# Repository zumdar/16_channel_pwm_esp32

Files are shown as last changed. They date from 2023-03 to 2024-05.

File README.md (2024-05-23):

# 16 Channel PWM led dimming board for ESP32

this repo contains the files for a 16 channel pcb to dim LEDS. 

## Description

I designed this board originally for my friend [Eddie Farr](https://www.instagram.com/freaughouse/?hl=en) for an led sculpture he is working on. I've also wanted something like this for a while to dim analog LED strips easily via WLED or ArtNet, or just plain old locally from a microcontroller.

It is designed to take in voltages from 5 to 37 Volts to power the ESP32. That way you can use this with 12 or 24 volt LEDs and dont have to deal with an extra 5V power supply to power the esp32. 

There are two separate places to put power in. 
EITHER plug 5V into the 5V side, or plug 7 - 37V into the other side. 
## pinout

LED1 = GPIO 5

LED2 = GPIO 12

LED3 = GPIO 13

LED4 = GPIO 14

LED5 = GPIO 15

LED6 = GPIO 16

LED7 = GPIO 17

LED8 = GPIO 18

LED9 = GPIO 19

LED10 = GPIO 21

LED11 = GPIO 22

LED12 = GPIO 23

LED13 = GPIO 25

LED14 = GPIO 26

LED15 = GPIO 27

LED16 = GPIO 32
## Schematic 
Rev 3
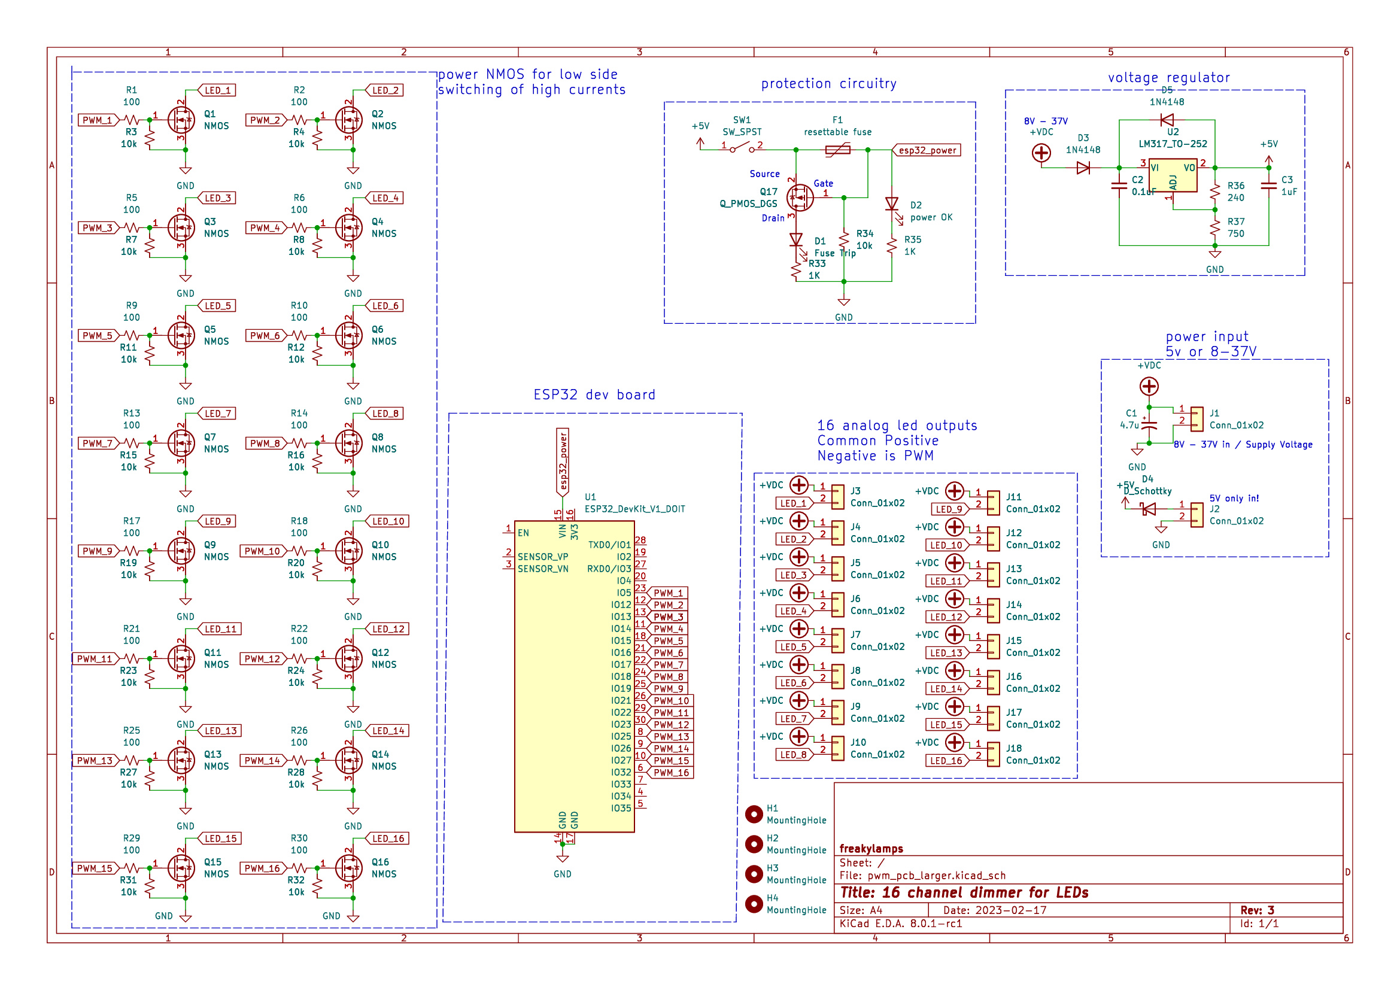
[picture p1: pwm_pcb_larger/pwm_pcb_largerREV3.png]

Rev 1 
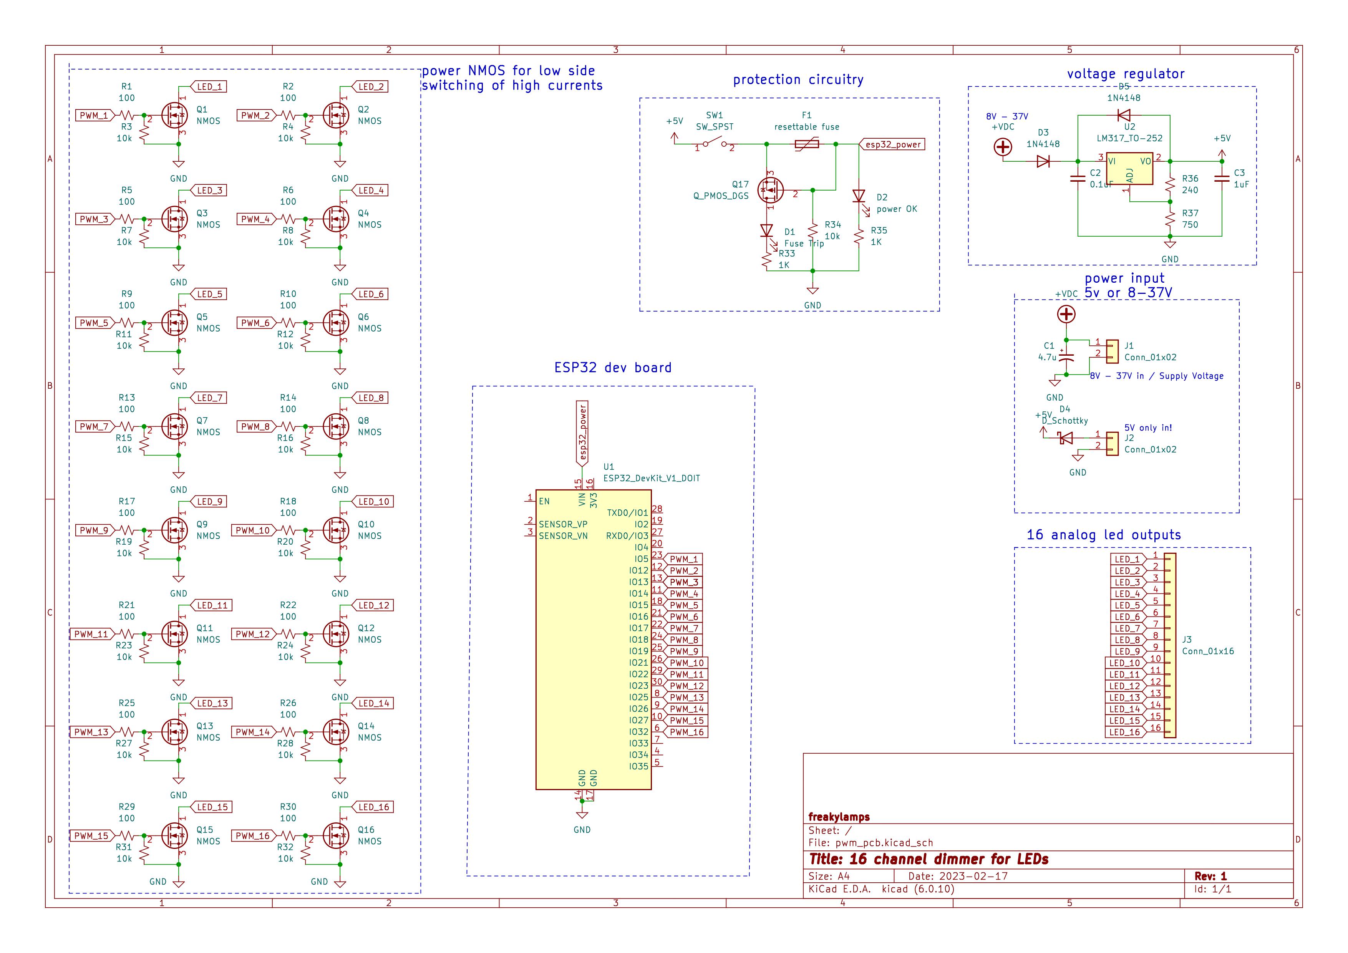
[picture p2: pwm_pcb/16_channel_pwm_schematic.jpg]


## PCB

Rev. 3 - pcb with larger transistors and larger connectors:

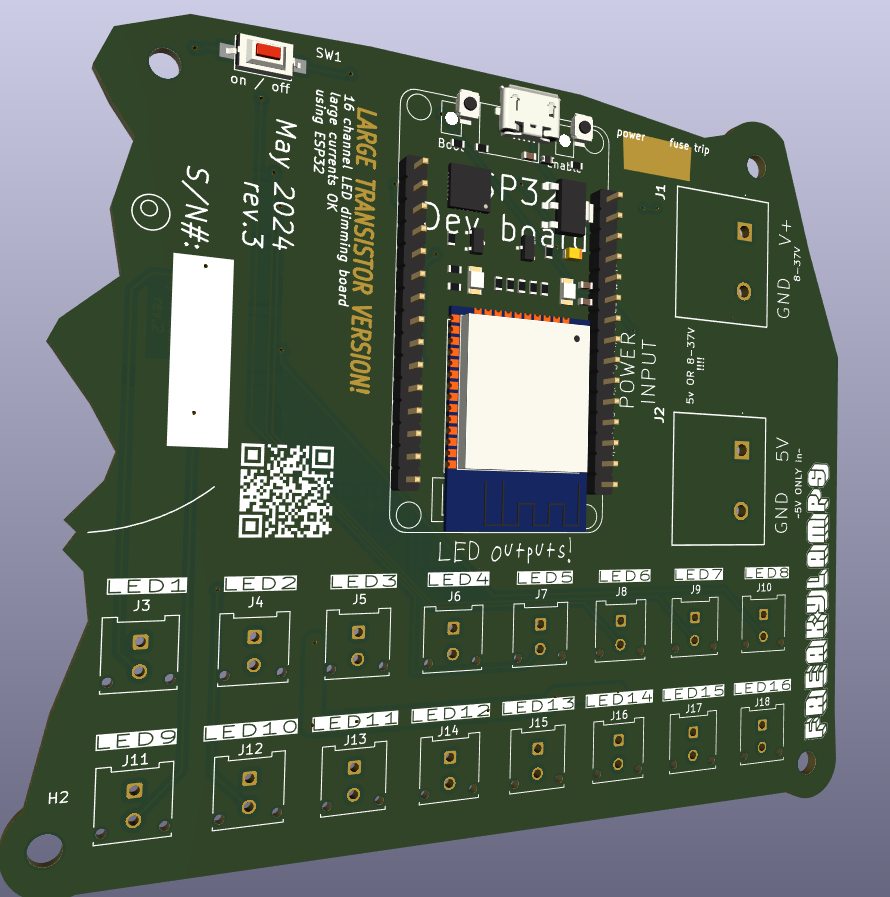
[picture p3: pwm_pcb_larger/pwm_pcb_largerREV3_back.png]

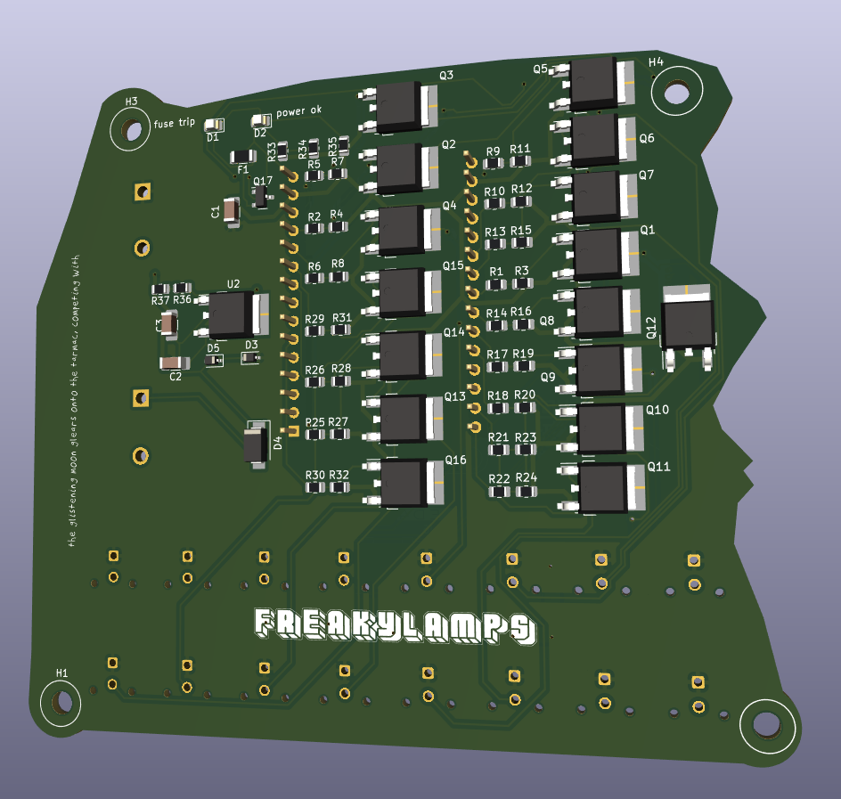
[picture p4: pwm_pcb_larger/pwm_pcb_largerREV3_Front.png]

Rev. 1 - pcb with larger transistors:

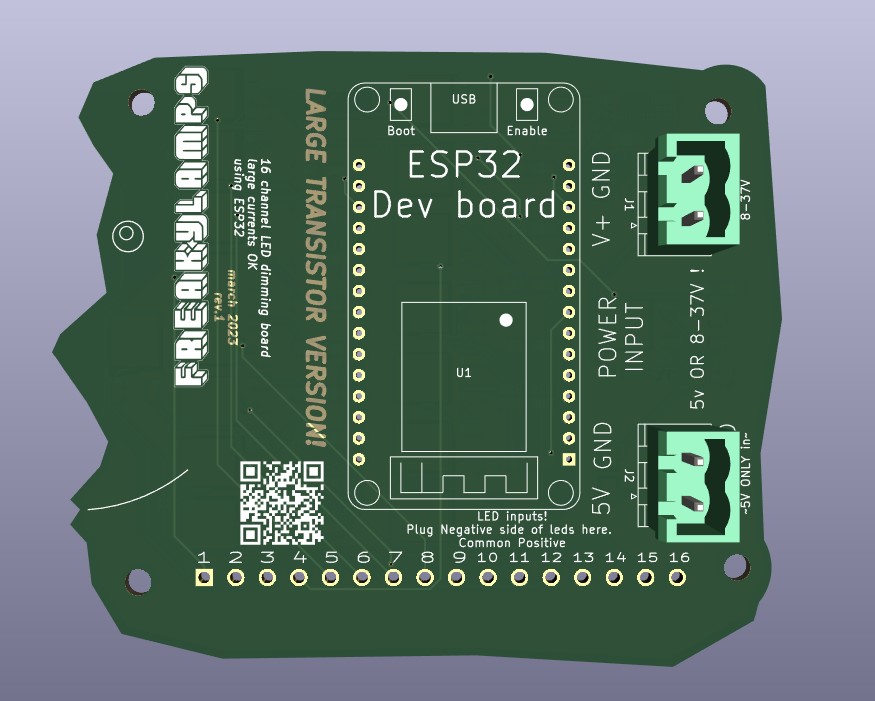
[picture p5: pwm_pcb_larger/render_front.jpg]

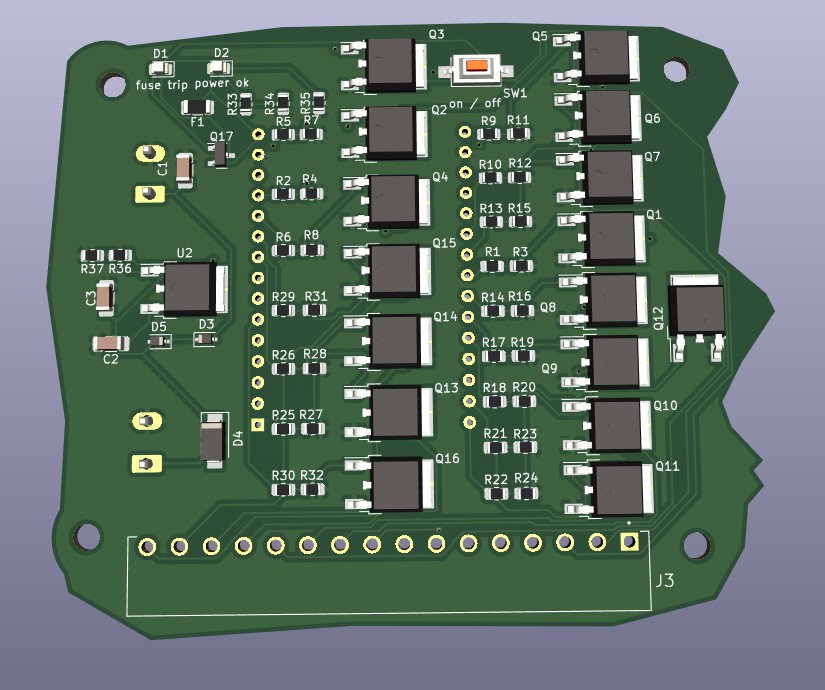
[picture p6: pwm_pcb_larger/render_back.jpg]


Rev. 1 - pcb with smaller transistors:

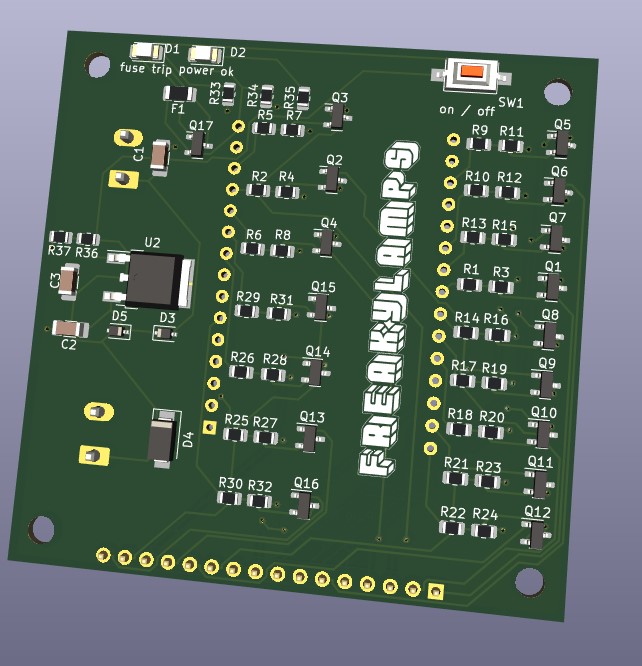
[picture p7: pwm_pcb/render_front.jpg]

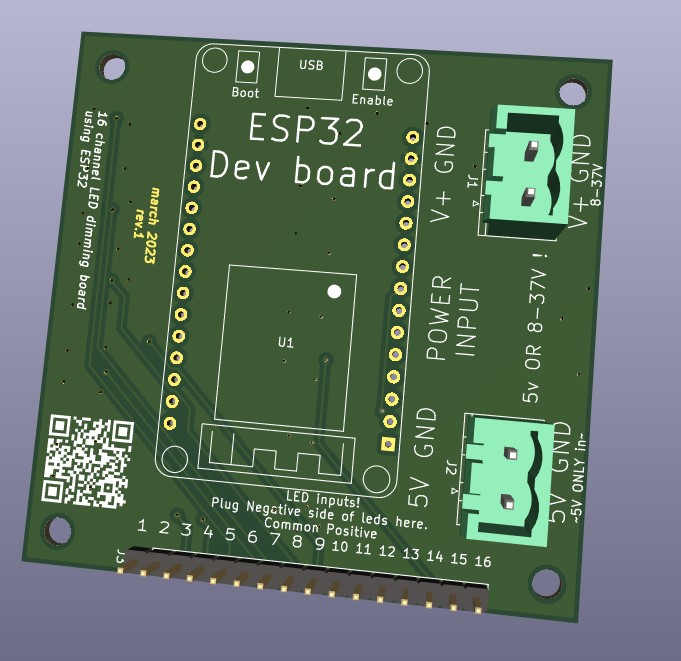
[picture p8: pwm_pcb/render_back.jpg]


## Parts references
### Connectors
- On version 1.3 we are trying out some Molex Microfit connectors
- Crimping tool - [Engineer PA09](https://www.amazon.com/ENGINEER-AWG32-AWG20-Connectors-Oil-Resistant-PA-09/dp/B002AVVO7K?th=1) 
- 
### Common parts
- [Mouser Cart](https://www.mouser.com/ProjectManager/ProjectDetail.aspx?AccessID=f114f2123e) for QTY 5 REV2 boards - this is parts not included with the JLCPCB assembly. 

- [Recommended Generic Crimper](https://www.amazon.com/ENGINEER-AWG32-AWG20-Connectors-Oil-Resistant-PA-09/dp/B002AVVO7K) for Molex Microfit Connectors

- using ESP-WROOM-32 dev board. 2.05" x 1.18" like the kind [found here](https://www.amazon.com/ESP-WROOM-32-Development-Microcontroller-Integrated-Compatible/dp/B0BK13HWBJ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)
- Both pcbs mount with M3 screws
- board has two places for power. one for 5V and one for 8V - 40V. The two connectors MSTBV/MSTBA Phoenix Type, 5.08 pitch. 
  - straight receptacle/header: [1747993 (green)](https://www.mouser.com/ProductDetail/Phoenix-Contact/1747993?qs=cq3Rj917t3li0%2FrJTXaRgg%3D%3D) or [1836561 (orange)](https://www.mouser.com/ProductDetail/Phoenix-Contact/1836561?qs=RahONj4mt5imYCprRrL9IA%3D%3D) or [1740893 (black)](https://www.mouser.com/ProductDetail/Phoenix-Contact/1740893?qs=o3rrLWFGhRnNm6PoJeAVCw%3D%3D)
  - right angle receptacle/header: [1736036 (green)](https://www.mouser.com/ProductDetail/Phoenix-Contact/1736036?qs=IGPQaF7TU6v9VVAvkUDQlA%3D%3D) or [1702878 (white)](https://www.mouser.com/ProductDetail/Phoenix-Contact/1702878?qs=2WS7V4AoKFqZwxKPPB6GZw%3D%3D) or [1876848 (orange)](https://www.mouser.com/ProductDetail/Phoenix-Contact/1876848?qs=KDxjV83btlSGzDlv5NRfLA%3D%3D)
  - terminal block plug: [Wurth 691351500002](https://www.mouser.com/ProductDetail/Wurth-Elektronik/691351500002?qs=7gQLVZk5cPkg%2FrpRGyiXgA%3D%3D) or [Kobiconn 158-P022ESDVP-E](https://www.mouser.com/ProductDetail/Kobiconn/158-P022ESDVP-E?qs=EibfsPFbZarDIylQPyTRxA%3D%3D) or [Amphenol TJ0251530000G](https://www.mouser.com/ProductDetail/Amphenol-Anytek/TJ0251530000G?qs=Mv7BduZupUjx%252Becl1KCPZg%3D%3D)
### larger pcb
- Enclosure mounts with #8 wood screws
-  the larger board uses 3.81mm pitch connector for led outputs
   - 16 channel plug -  pluggable screw terminal block - [TBP02P1-381-16BE](https://www.mouser.com/ProductDetail/490-TBP02P1-381-16BE) 
   - screw terminal receptacle/header 
[TBP02R1-381-16BE](https://www.mouser.com/ProductDetail/490-TBP02R1-381-16BE)
### smaller pcb
- smaller board uses 2.54mm connector for led outputs

## Help

Any advise for common problems or issues.

## Authors

[william kennedy](https://freakylamps.com/)

## Version History

* 1.0
    * Initial Release - March 15, 2023
* 1.1
    * new design with larger TO-252 package for NMOS - March 20, 2023
* 1.2 - april 5, 2023
  * v2 of smaller board. v1 had NMOS pinout wrong
* Rev 3 - May 22, 2024
  * large boards are now larger, using MicroFit connectors for the led outputs, terminal block for PSU inputs
  * switch is on front now
  * Q17 had pinout wrong

## License

This project is licensed under the [NAME HERE] License - see the LICENSE.md file for details

## Acknowledgments

Inspiration comes from [quinLED's analog boards](https://quinled.info/quinled-an-quad/)

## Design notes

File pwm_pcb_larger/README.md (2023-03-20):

# 16 Channel PWM led dimming board for ESP32 - larger version with TO252 package

this repo contains the files for a 16 channel pcb to dim leds using TO-252 NMOS package for more current. 

## use case 
- WLED to dim analog LED strips
- ArtNet dmx over wifi to the ESP32 to control 16 channels of led wirelessly

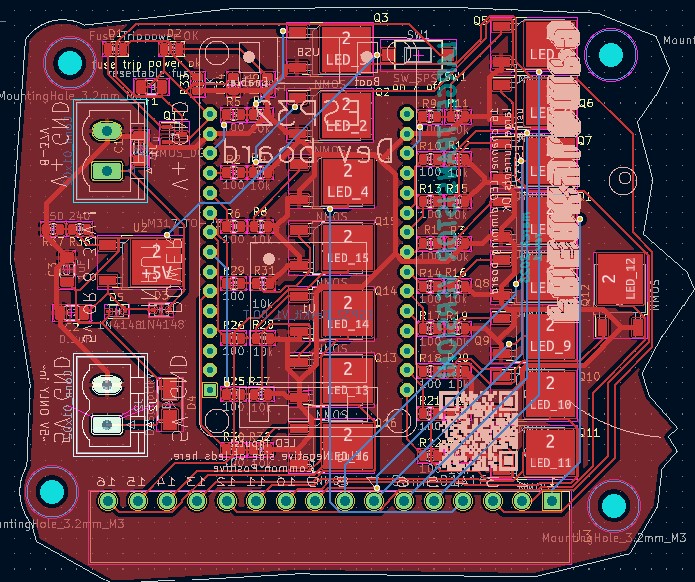
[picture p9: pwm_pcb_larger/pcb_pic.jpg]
pwm_pcb with larger transistors


## Author

[william kennedy](https://freakylamps.com/)

## Version History

* 1.1
    * Initial Release - March 20, 2023

## License

This project is licensed under the [NAME HERE] License - see the LICENSE.md file for details

## Acknowledgments

Inspiration comes from [quinLED's analog boards](https://quinled.info/quinled-an-quad/)

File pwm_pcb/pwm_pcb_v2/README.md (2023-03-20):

# 16 Channel PWM led dimming board for ESP32 - smaller version with SOT23 NMOS 

this repo contains the files for a 16 channel pcb to dim leds using sot23 NMOS package for less current. 

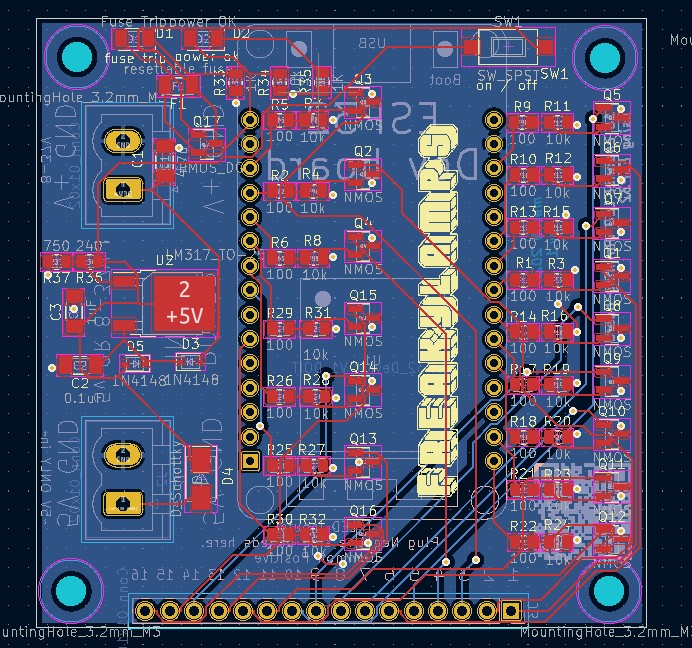
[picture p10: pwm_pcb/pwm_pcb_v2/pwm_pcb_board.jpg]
pwm pcb board


front

back

## Authors

[william kennedy](https://freakylamps.com/)

## Version History

* 1.0
    * Initial Release - March 15, 2023

## License

This project is licensed under the [NAME HERE] License - see the LICENSE.md file for details

## Acknowledgments

Inspiration, code snippets, etc.

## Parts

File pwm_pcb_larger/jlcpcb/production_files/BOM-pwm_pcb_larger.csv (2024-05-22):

Comment | Designator | Footprint | LCSC
Q_PMOS_DGS | Q17 | SOT-23 | C15127
100 | R1,R10,R13,R14,R17,R18,R2,R21,R22,R25,R26,R29,R30,R5,R6,R9 | R_0805_2012Metric | C17408
10k | R11,R12,R15,R16,R19,R20,R23,R24,R27,R28,R3,R31,R32,R34,R4,R7,R8 | R_0805_2012Metric | C17414
1K | R33,R35 | R_0805_2012Metric | C17513
240 | R36 | R_0805_2012Metric | C17572
750 | R37 | R_0805_2012Metric | C17818
1uF | C3 | C_1206_3216Metric_Pad1.33x1.80mm_HandSolder | C1848
1N4148 | D3,D5 | D_SOD-323 | C2128
0.1uF | C2 | C_1206_3216Metric_Pad1.33x1.80mm_HandSolder | C24497
D_Schottky | D4 | D_SMA | C2480
4.7u | C1 | C_1206_3216Metric_Pad1.33x1.80mm_HandSolder | C29823
NMOS | Q1,Q10,Q11,Q12,Q13,Q14,Q15,Q16,Q2,Q3,Q4,Q5,Q6,Q7,Q8,Q9 | TO-252-2 | C2995345
power OK | D2 | LED_0805_2012Metric | C34499
SW_SPST | SW1 | SW_SPST_CK_RS282G05A3 | C54948
resettable fuse | F1 | Fuse_1206_3216Metric | C70077
LM317_TO-252 | U2 | TO-252-2 | C75510
Fuse Trip | D1 | LED_0805_2012Metric | C84256
Conn_01x02 | J3 | Molex_Micro-Fit_3.0_43045-0212_2x01_P3.00mm_Vertical
Conn_01x02 | J2 | Kobiconn - 2 pin terminal - 158P02DT39BE
Conn_01x02 | J1 | Kobiconn - 2 pin terminal - 158P02DT39BE
ESP32_DevKit_V1_DOIT | U1 | esp32_devkit_v1_doit
Conn_01x02 | J9 | Molex_Micro-Fit_3.0_43045-0212_2x01_P3.00mm_Vertical
Conn_01x02 | J13 | Molex_Micro-Fit_3.0_43045-0212_2x01_P3.00mm_Vertical
Conn_01x02 | J4 | Molex_Micro-Fit_3.0_43045-0212_2x01_P3.00mm_Vertical
Conn_01x02 | J15 | Molex_Micro-Fit_3.0_43045-0212_2x01_P3.00mm_Vertical
Conn_01x02 | J6 | Molex_Micro-Fit_3.0_43045-0212_2x01_P3.00mm_Vertical
Conn_01x02 | J11 | Molex_Micro-Fit_3.0_43045-0212_2x01_P3.00mm_Vertical
Conn_01x02 | J17 | Molex_Micro-Fit_3.0_43045-0212_2x01_P3.00mm_Vertical
Conn_01x02 | J14 | Molex_Micro-Fit_3.0_43045-0212_2x01_P3.00mm_Vertical
Conn_01x02 | J12 | Molex_Micro-Fit_3.0_43045-0212_2x01_P3.00mm_Vertical
Conn_01x02 | J8 | Molex_Micro-Fit_3.0_43045-0212_2x01_P3.00mm_Vertical
Conn_01x02 | J7 | Molex_Micro-Fit_3.0_43045-0212_2x01_P3.00mm_Vertical
Conn_01x02 | J10 | Molex_Micro-Fit_3.0_43045-0212_2x01_P3.00mm_Vertical
Conn_01x02 | J18 | Molex_Micro-Fit_3.0_43045-0212_2x01_P3.00mm_Vertical
Conn_01x02 | J16 | Molex_Micro-Fit_3.0_43045-0212_2x01_P3.00mm_Vertical
Conn_01x02 | J5 | Molex_Micro-Fit_3.0_43045-0212_2x01_P3.00mm_Vertical

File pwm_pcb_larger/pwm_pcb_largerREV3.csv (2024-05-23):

Reference | Value | Datasheet | Footprint | Qty | LCSC | Part Number | Mouser Link
C1 | 4.7u | ~ | Capacitor_SMD:C_1206_3216Metric_Pad1.33x1.80mm_HandSolder | 1 | C29823
C2 | 0.1uF | ~ | Capacitor_SMD:C_1206_3216Metric_Pad1.33x1.80mm_HandSolder | 1 | C24497
C3 | 1uF | ~ | Capacitor_SMD:C_1206_3216Metric_Pad1.33x1.80mm_HandSolder | 1 | C1848
D1 | Fuse Trip | ~ | LED_SMD:LED_0805_2012Metric | 1 | C84256
D2 | power OK | ~ | LED_SMD:LED_0805_2012Metric | 1 | C34499
D3,D5 | 1N4148 | https://assets.nexperia.com/documents/data-sheet/1N4148_1N4448.pdf | Diode_SMD:D_SOD-323 | 2 | C2128
D4 | D_Schottky | ~ | Diode_SMD:D_SMA | 1 | C2480
F1 | resettable fuse | ~ | Fuse:Fuse_1206_3216Metric | 1 | C70077
J1,J2 | Conn_01x02 | ~ | william customs:Kobiconn - 2 pin terminal - 158P02DT39BE | 2 |  | 158-P02DT39B-E | https://www.mouser.com/ProductDetail/Kobiconn/158-P02DT39B-E?qs=sU0fTKI0LumyQ7Jmuo1Jcw%3D%3D
J3,J4,J5,J6,J7,J8,J9,J10,J11,J12,J13,J14,J15,J16,J17,J18 | Conn_01x02 | ~ | Connector_Molex:Molex_Micro-Fit_3.0_43045-0212_2x01_P3.00mm_Vertical | 16 |  | 43045-0212 | https://www.mouser.com/ProductDetail/Molex/43045-0212?qs=QtQX4uD3c2XFLtjr%252BHeRmQ%3D%3D
Q1,Q2,Q3,Q4,Q5,Q6,Q7,Q8,Q9,Q10,Q11,Q12,Q13,Q14,Q15,Q16 | NMOS | ~ | Package_TO_SOT_SMD:TO-252-2 | 16 | C2995345
Q17 | Q_PMOS_DGS | ~ | Package_TO_SOT_SMD:SOT-23 | 1 | C15127
R1,R2,R5,R6,R9,R10,R13,R14,R17,R18,R21,R22,R25,R26,R29,R30 | 100 | ~ | Resistor_SMD:R_0805_2012Metric | 16 | C17408
R3,R4,R7,R8,R11,R12,R15,R16,R19,R20,R23,R24,R27,R28,R31,R32,R34 | 10k | ~ | Resistor_SMD:R_0805_2012Metric | 17 | C17414
R33,R35 | 1K | ~ | Resistor_SMD:R_0805_2012Metric | 2 | C17513
R36 | 240 | ~ | Resistor_SMD:R_0805_2012Metric | 1 | C17572
R37 | 750 | ~ | Resistor_SMD:R_0805_2012Metric | 1 | C17818
SW1 | SW_SPST | ~ | Button_Switch_SMD:SW_SPST_CK_RS282G05A3 | 1 | C54948 | CFS-0102TB | https://www.mouser.com/ProductDetail/Nidec-Components/CFS-0102TB?qs=XeJtXLiO41Q%2F6gtnIMuqpA%3D%3D
U1 | ESP32_DevKit_V1_DOIT | https://aliexpress.com/item/32864722159.html | Espressif:esp32_devkit_v1_doit | 1 |  |  | https://www.amazon.com/ESP-WROOM-32-Development-Microcontroller-Integrated-Compatible/dp/B0BK13HWBJ
U2 | LM317_TO-252 | http://www.ti.com/lit/ds/snvs774n/snvs774n.pdf | Package_TO_SOT_SMD:TO-252-2 | 1 | C75510
Special Items
Generic Molex Microfit Crimper |  |  | can crimp wires AWG32 - AWG 20 | 1 |  | Engineer PA-09 | https://www.amazon.com/ENGINEER-AWG32-AWG20-Connectors-Oil-Resistant-PA-09/dp/B002AVVO7K
Molex Micofit socket (female) connectors |  |  |  | 16 |  | 43025-0200 | https://www.mouser.com/ProductDetail/Molex/43025-0200?qs=4XSMV6Twtb2B3B7qTwcqgQ%3D%3D
Molex Micofit socket (female) crimp connectors |  |  |  | 32 |  | 43030-0001 | https://www.mouser.com/ProductDetail/Molex/43030-0001-Cut-Strip?qs=LVm7ROZMjqOG%2FpR3agpKGQ%3D%3D

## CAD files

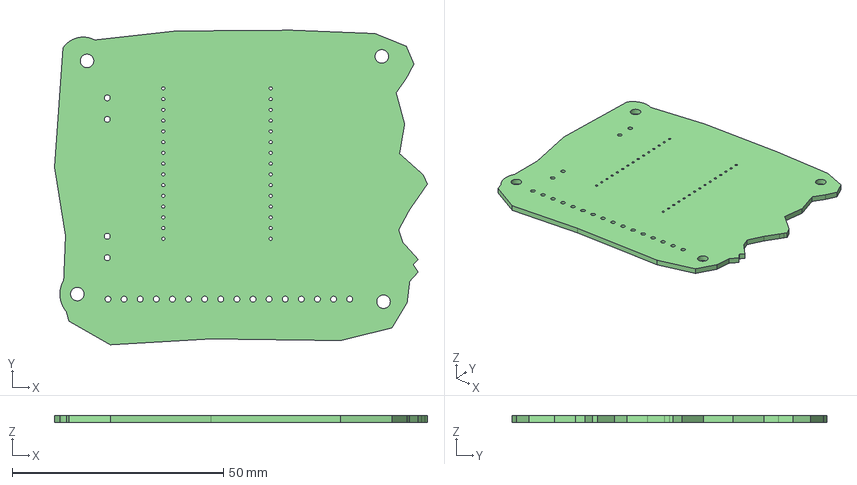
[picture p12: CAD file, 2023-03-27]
pwm_pcb_larger/pwm_pcb_larger.step
88.2 x 74.4 x 1.60 mm

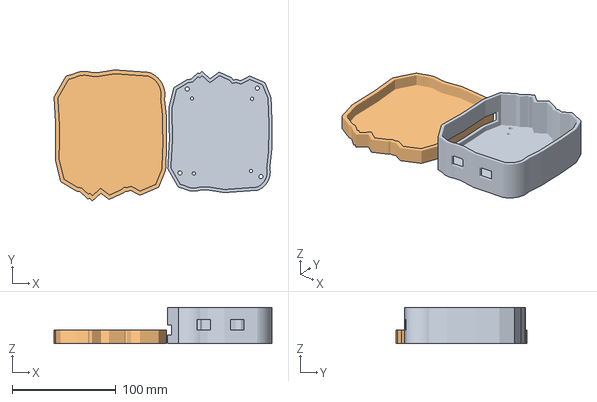
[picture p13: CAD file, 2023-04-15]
pwmpcb_v3_w3mmToleranceLID.3mf
210.3 x 126.5 x 34.8 mm
lower.stl
lid.stl

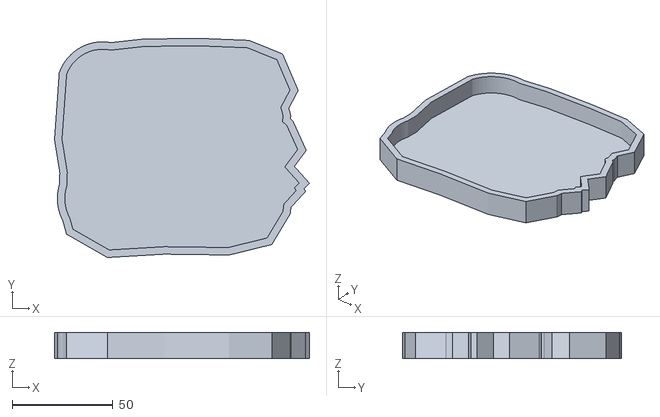
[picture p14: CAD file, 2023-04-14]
lid_w3mmToleranc.stl
126.5 x 108.7 x 13.0

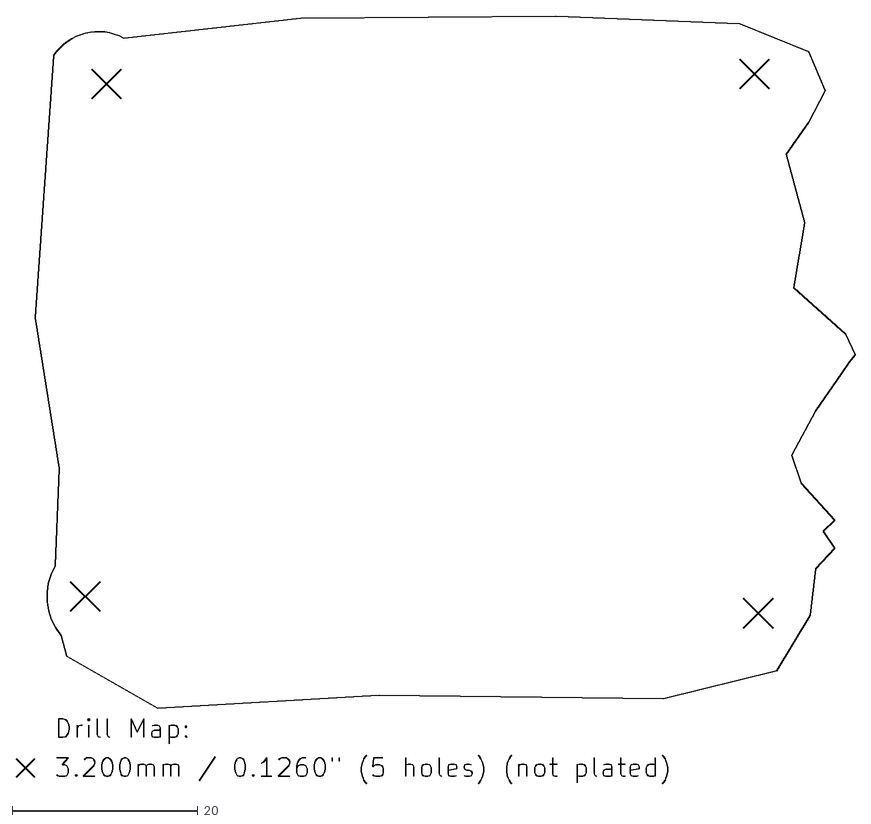
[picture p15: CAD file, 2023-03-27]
pwm_pcb_larger/pwm_pcb_larger-NPTH-drl_map.dxf
90.2 x 82.5

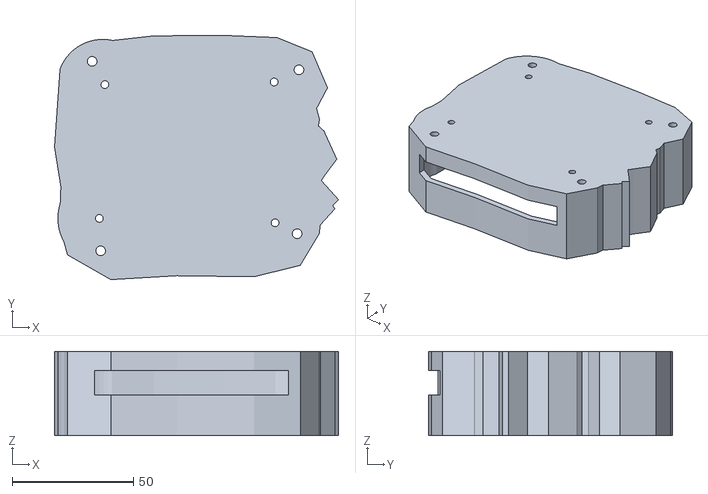
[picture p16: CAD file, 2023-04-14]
larger_enclosure_base.stl
117.0 x 100.6 x 34.8

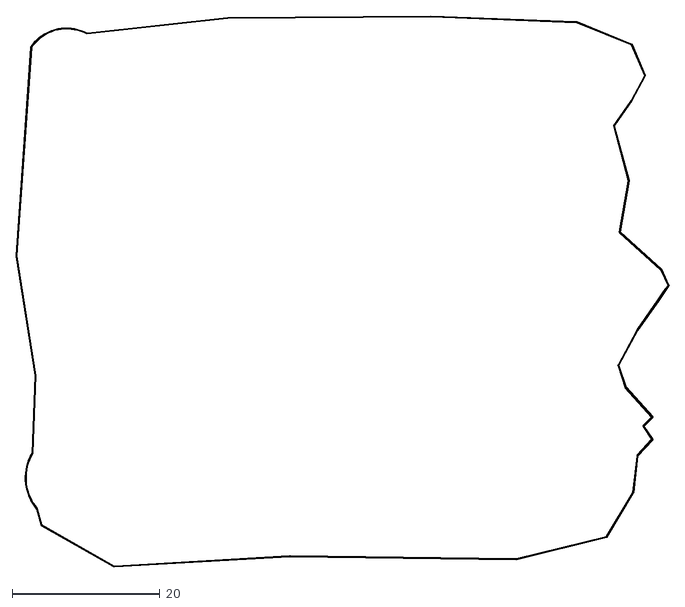
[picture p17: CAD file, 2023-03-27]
pwm_pcb_larger/pwm_pcb_larger-Edge_Cuts.dxf
88.3 x 74.5

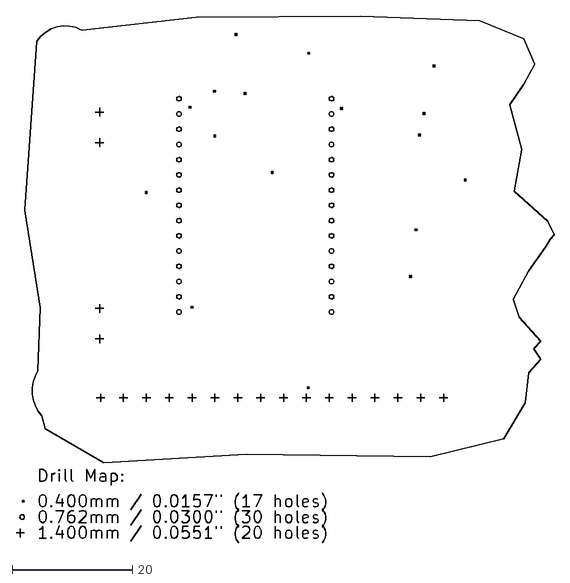
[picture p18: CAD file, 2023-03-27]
pwm_pcb_larger/pwm_pcb_larger-PTH-drl_map.dxf
89.6 x 87.8

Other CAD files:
larger_enclosure_lid.stl
base_w3mmTolerance.stl
PCBPWM_v2 v1.f3d
PCBPWM_v2.f3d

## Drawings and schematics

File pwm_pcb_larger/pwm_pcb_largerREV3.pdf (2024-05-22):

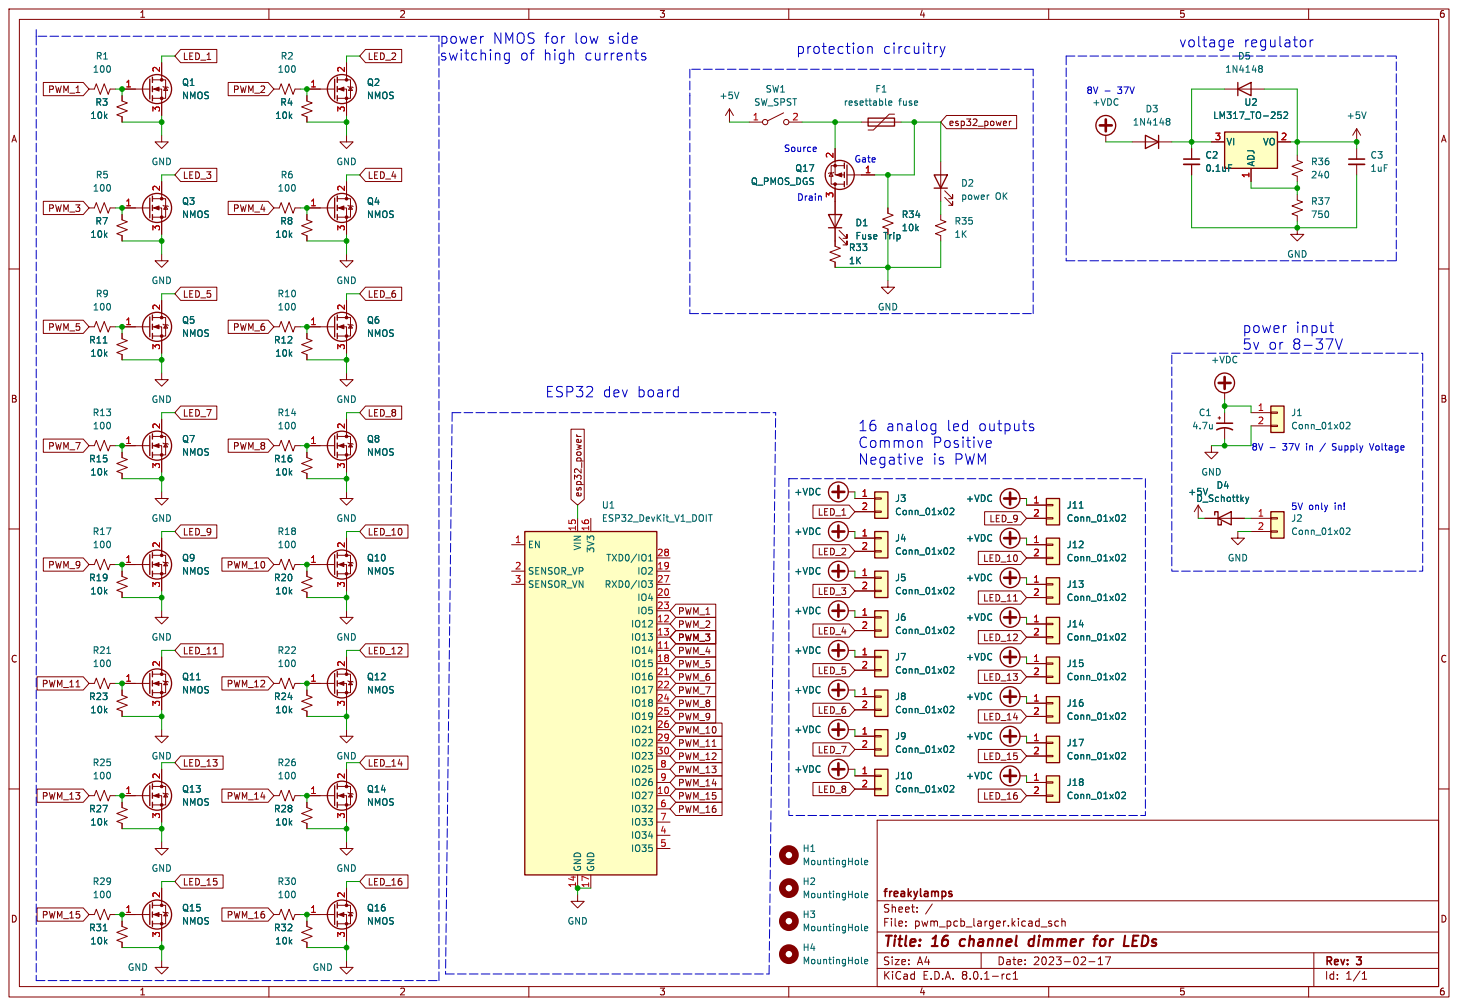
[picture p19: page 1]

voltage regulator 8V - 37V ESP32 dev board

5V only in! power input

H4 MountingHole H2 MountingHole H3 MountingHole H1 MountingHole PWM_8 PWM_10

Id: 1/1 Title: 16 channel dimmer for LEDs

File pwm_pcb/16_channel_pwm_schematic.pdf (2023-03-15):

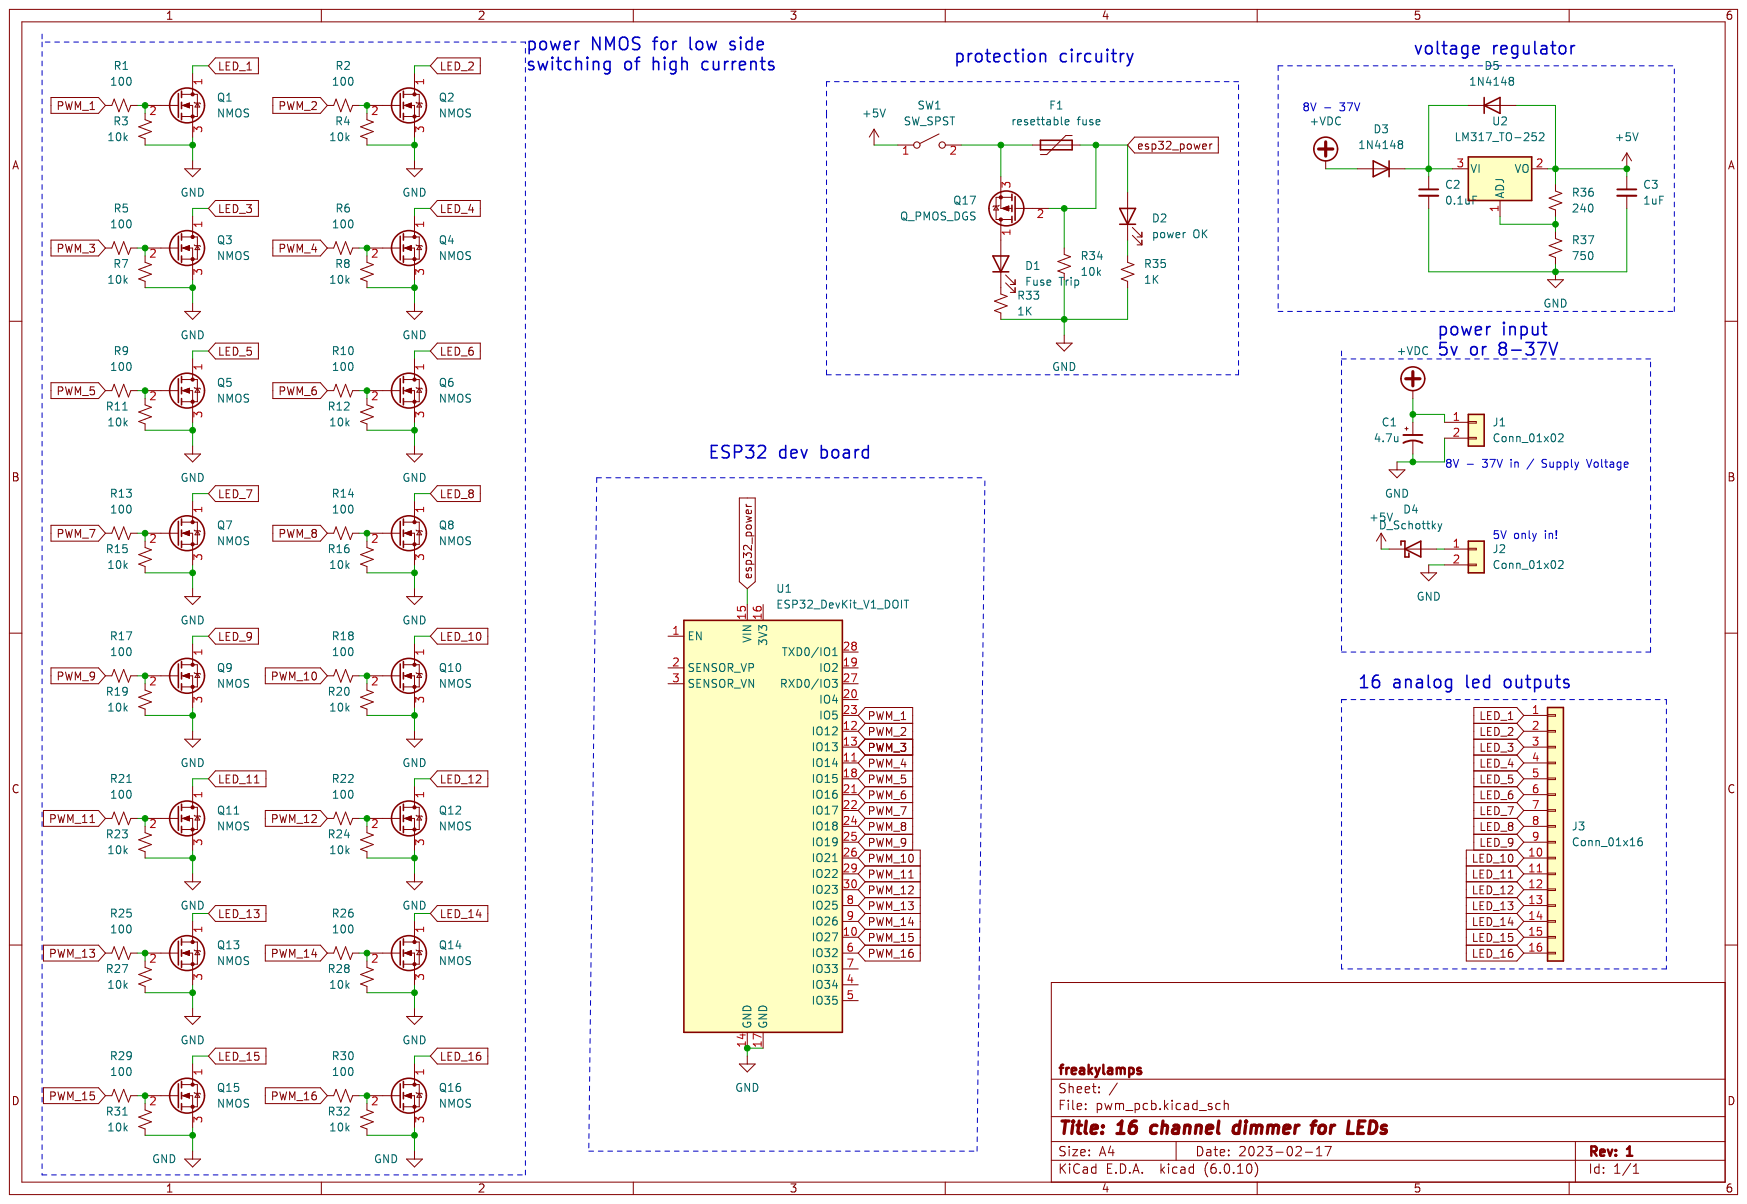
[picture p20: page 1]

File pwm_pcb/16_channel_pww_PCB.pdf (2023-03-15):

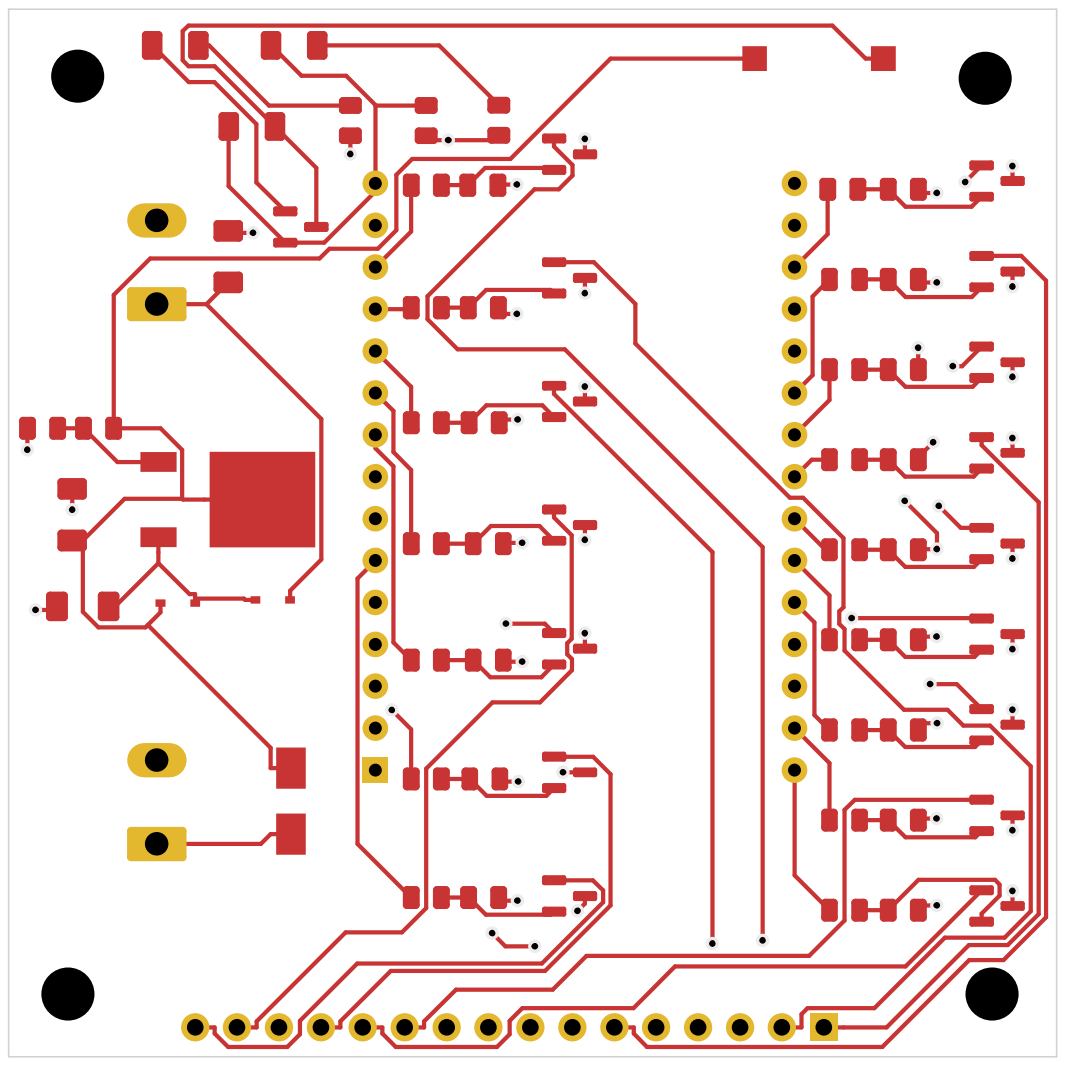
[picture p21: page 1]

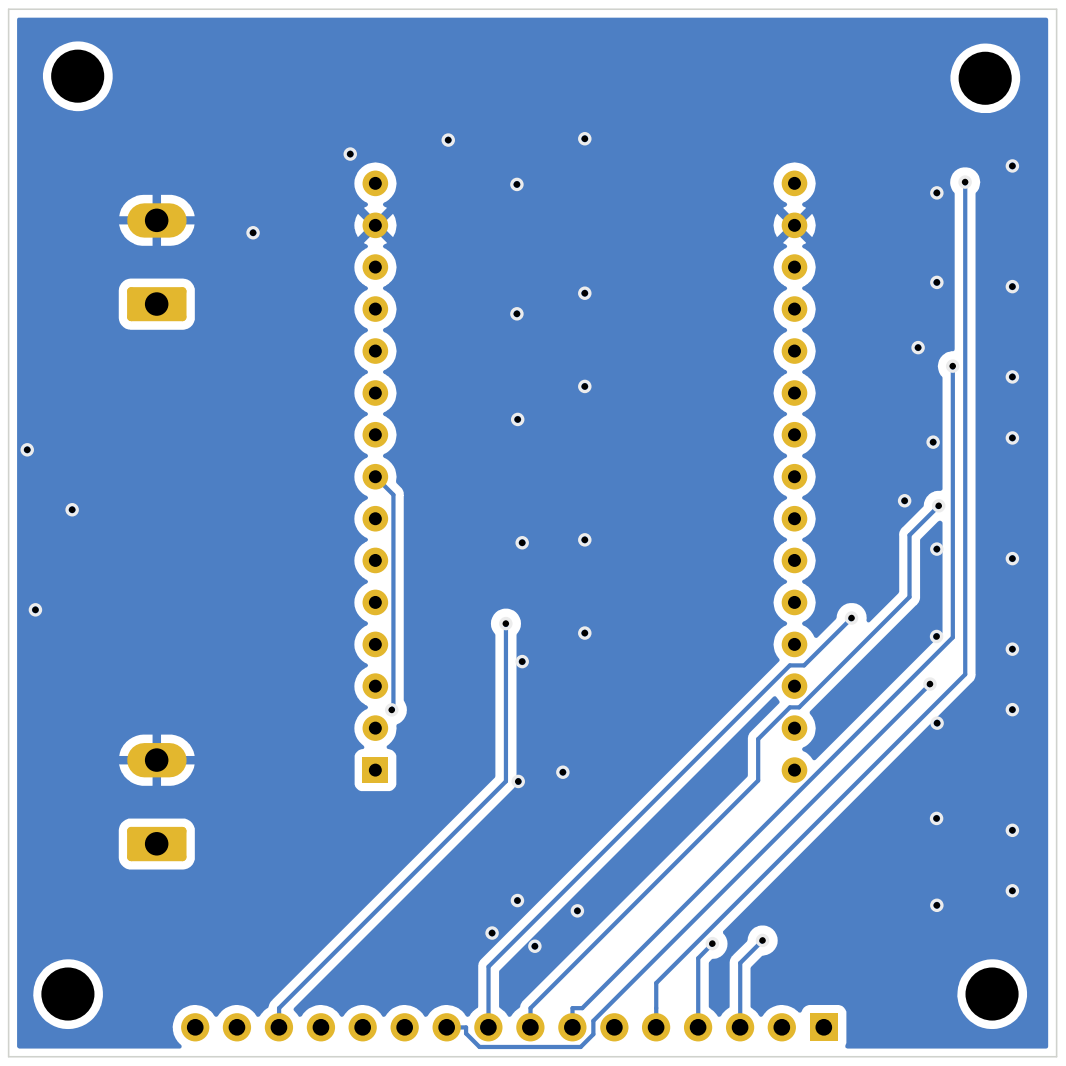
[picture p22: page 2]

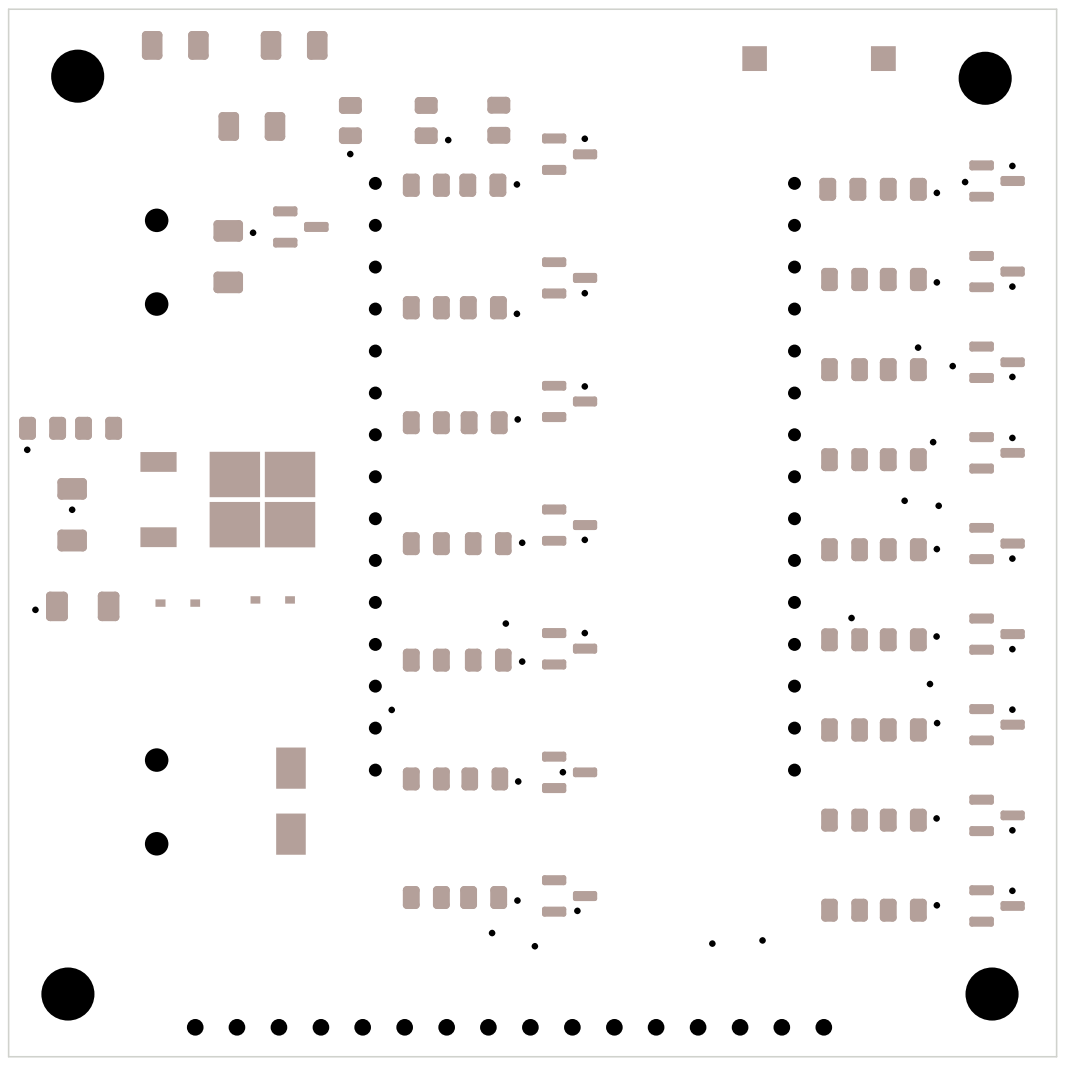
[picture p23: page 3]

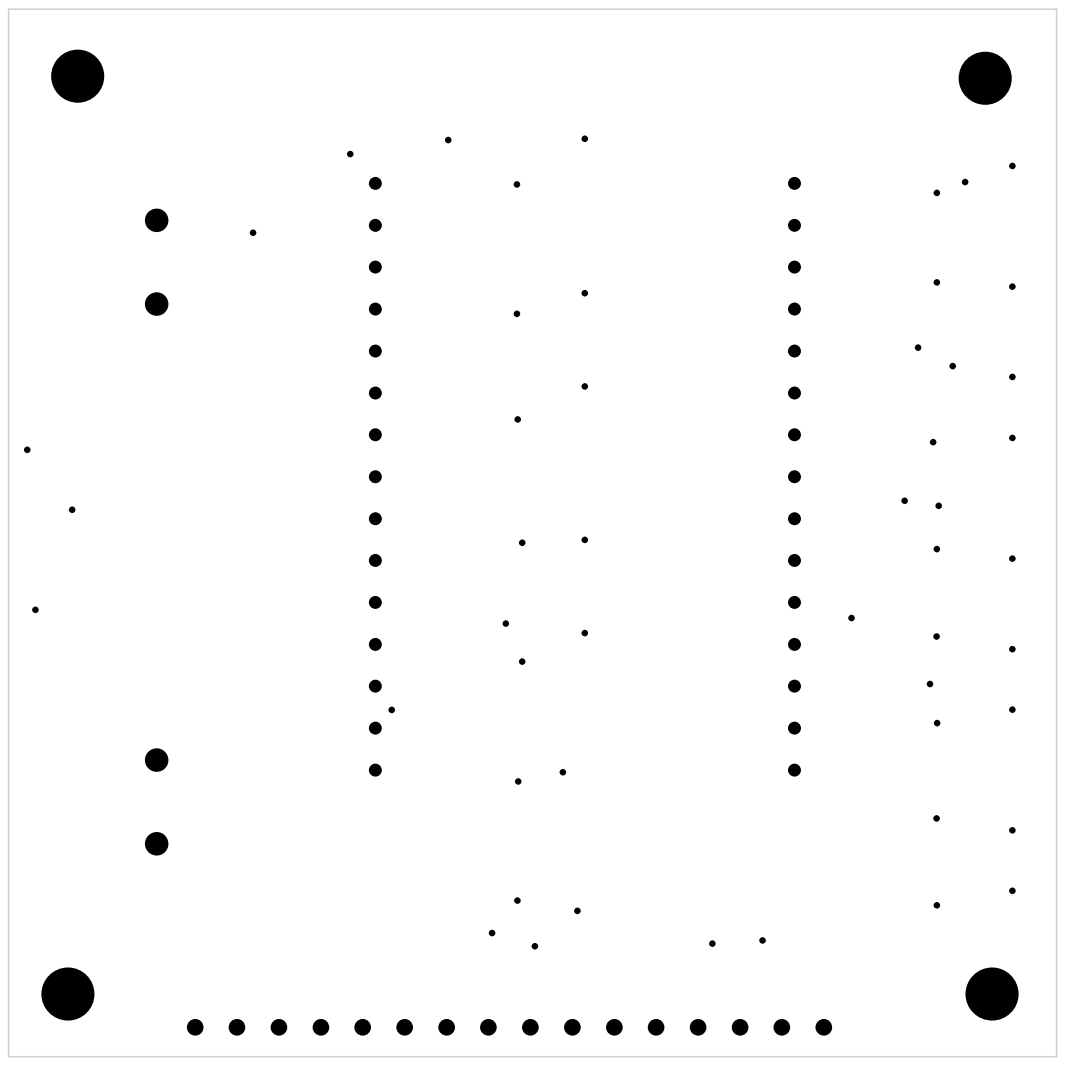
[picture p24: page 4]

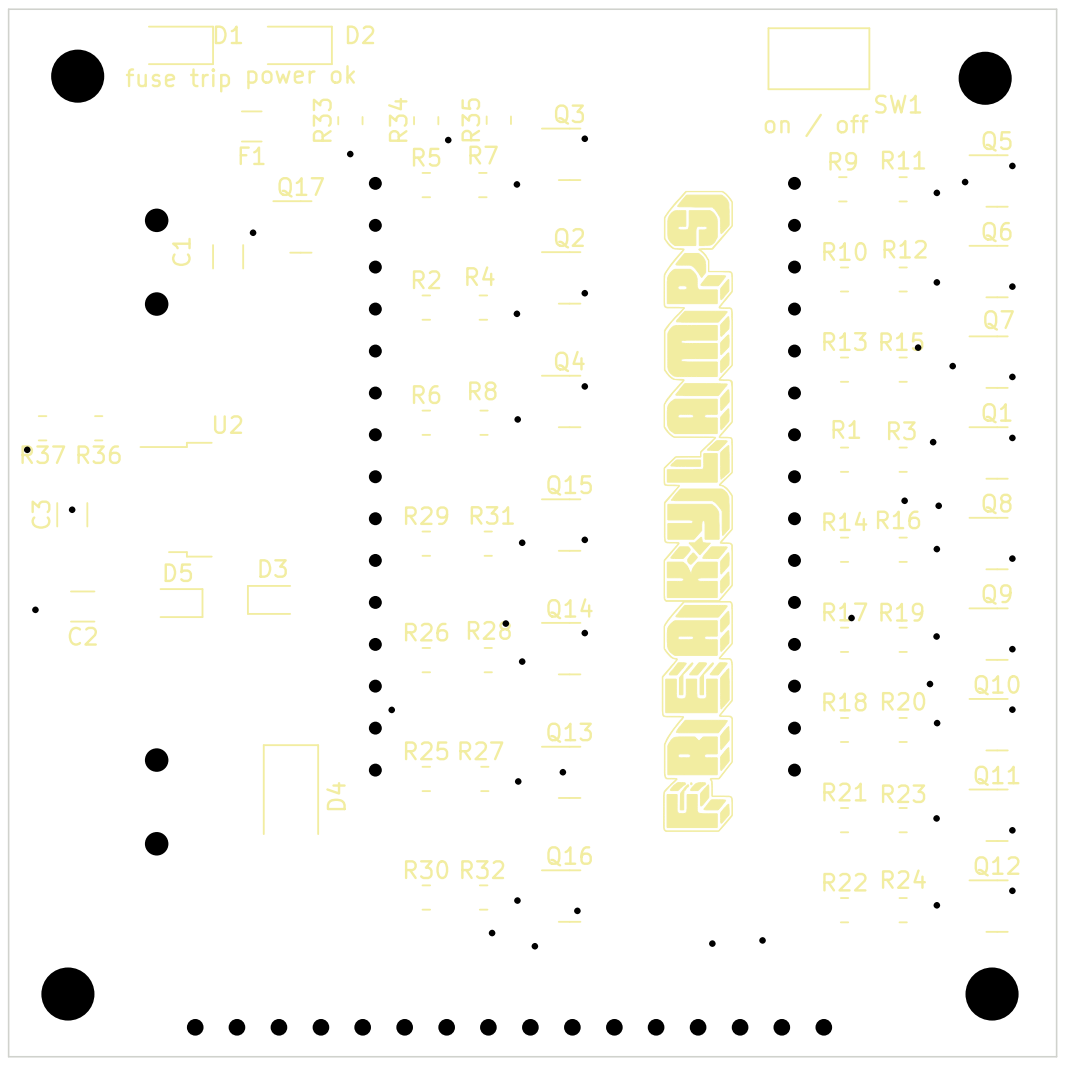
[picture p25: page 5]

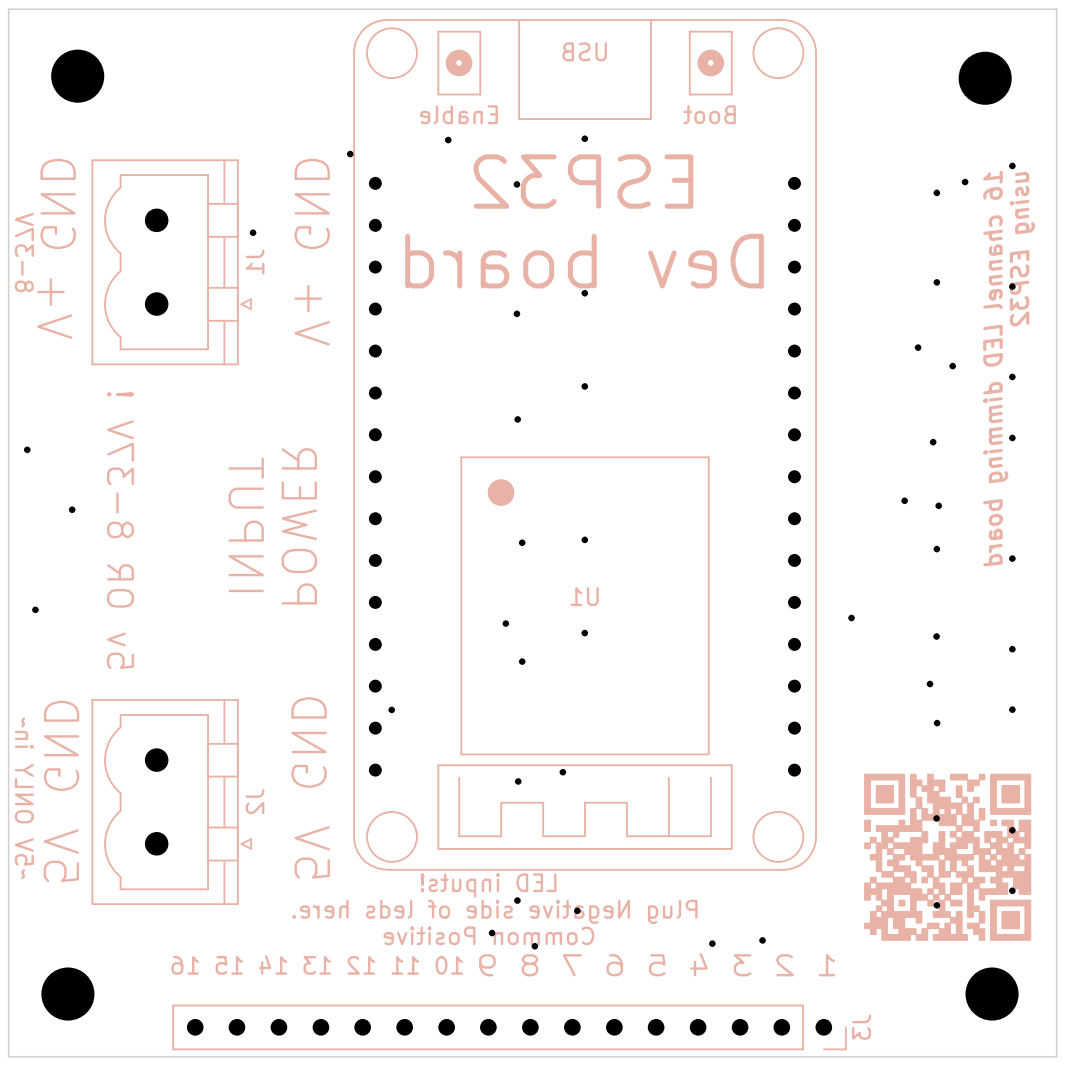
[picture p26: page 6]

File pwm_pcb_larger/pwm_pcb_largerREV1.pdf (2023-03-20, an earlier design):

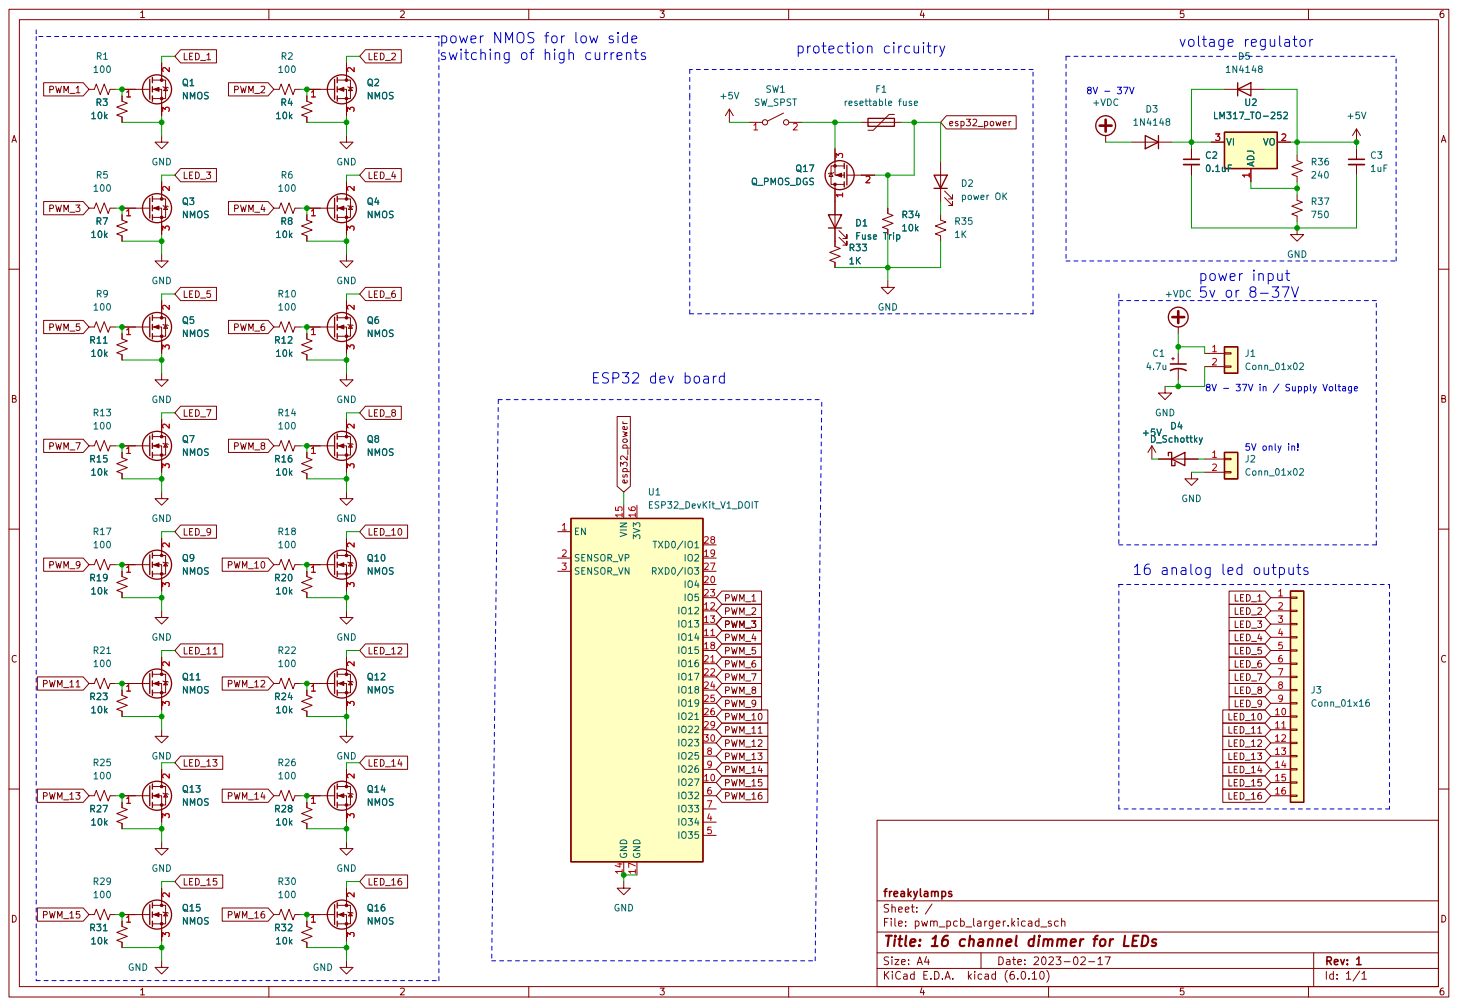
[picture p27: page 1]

voltage regulator protection circuitry power NMOS for low side
switching of high currents

Id: 1/1 Title: 16 channel dimmer for LEDs

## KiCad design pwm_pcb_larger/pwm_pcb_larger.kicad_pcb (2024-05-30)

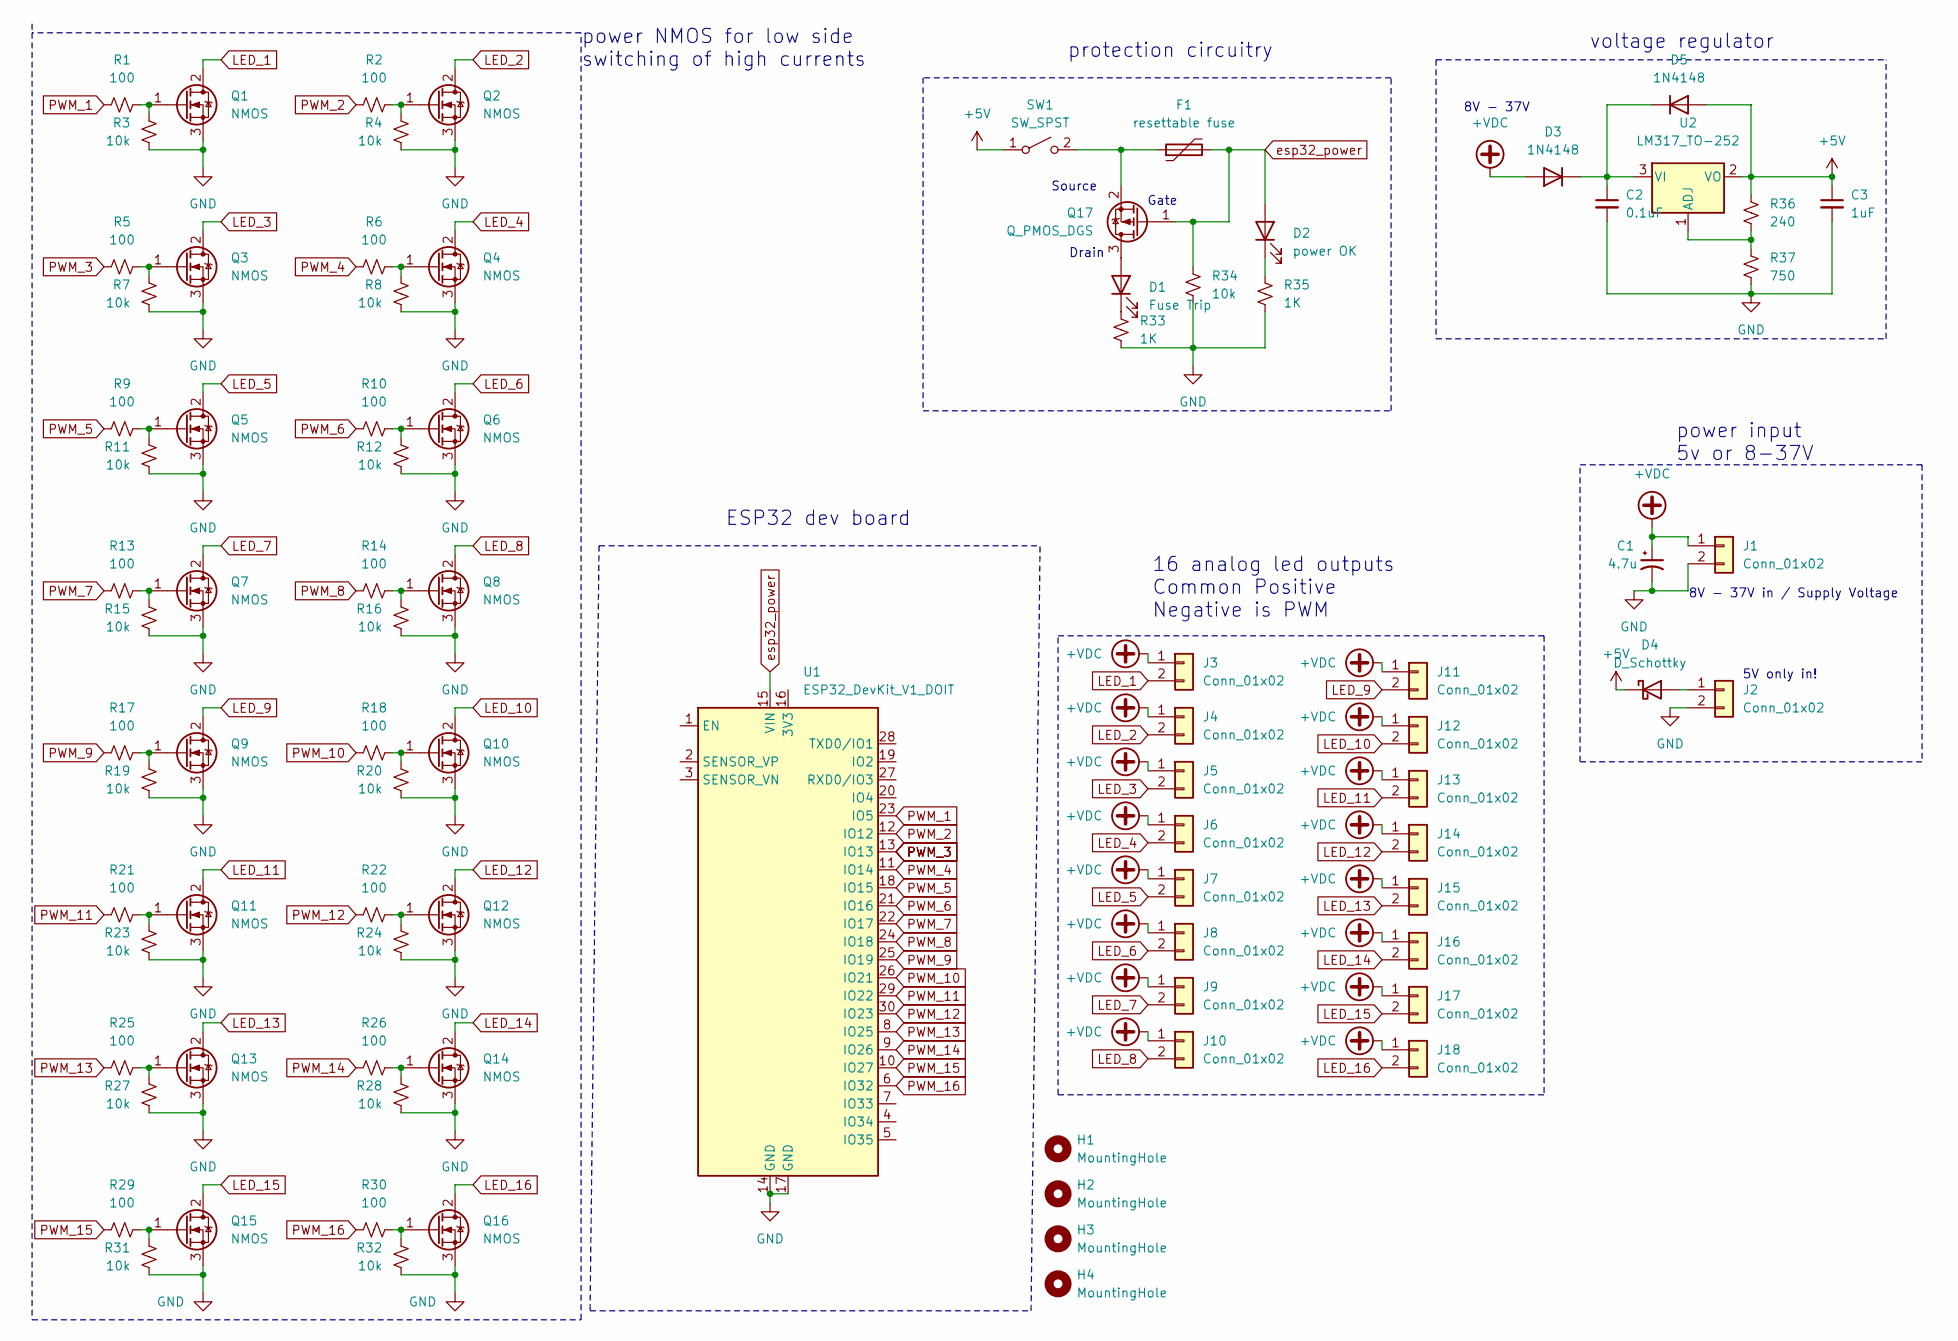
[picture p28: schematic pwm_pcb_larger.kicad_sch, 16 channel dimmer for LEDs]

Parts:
C1: 4.7u; C_1206_3216Metric_Pad1.33x1.80mm_HandSolder; LCSC C29823
C2: 0.1uF; C_1206_3216Metric_Pad1.33x1.80mm_HandSolder; LCSC C24497
C3: 1uF; C_1206_3216Metric_Pad1.33x1.80mm_HandSolder; LCSC C1848
D1: Fuse Trip; LED_0805_2012Metric; LCSC C84256
D2: power OK; LED_0805_2012Metric; LCSC C34499
D3, D5: 1N4148; D_SOD-323; LCSC C2128
D4: D_Schottky; D_SMA; LCSC C2480
F1: resettable fuse; Fuse_1206_3216Metric; LCSC C70077
H1, H2, H3, H4: MountingHole; MountingHole_3.2mm_M3
J1, J2: Conn_01x02; Kobiconn - 2 pin terminal - 158P02DT39BE
J3, J4, J5, J6, J7, J8, J9, J10, J11, J12, J13, J14, J15, J16, J17, J18: Conn_01x02; Molex_Micro-Fit_3.0_43045-0212_2x01_P3.00mm_Vertical
Q1, Q2, Q3, Q4, Q5, Q6, Q7, Q8, Q9, Q10, Q11, Q12, Q13, Q14, Q15, Q16: NMOS; TO-252-2; LCSC C2995345
Q17: Q_PMOS_DGS; SOT-23; LCSC C15127
R1, R2, R5, R6, R9, R10, R13, R14, R17, R18, R21, R22, R25, R26, R29, R30: 100; R_0805_2012Metric; LCSC C17408
R3, R4, R7, R8, R11, R12, R15, R16, R19, R20, R23, R24, R27, R28, R31, R32, R34: 10k; R_0805_2012Metric; LCSC C17414
R33, R35: 1K; R_0805_2012Metric; LCSC C17513
R36: 240; R_0805_2012Metric; LCSC C17572
R37: 750; R_0805_2012Metric; LCSC C17818
SW1: SW_SPST; SW_SPST_CK_RS282G05A3; LCSC C54948
U1: ESP32_DevKit_V1_DOIT; esp32_devkit_v1_doit
U2: LM317_TO-252; TO-252-2; LCSC C75510

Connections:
+5V: C3.1, D4.1 (K), D5.2 (A), R36.1, SW1.1 (A), U2.2 (VO)
+VDC: C1.1, D3.2 (A), J1.1, J3.1, J4.1, J5.1, J6.1, J7.1, J8.1, J9.1, J10.1, J11.1, J12.1, J13.1, J14.1, J15.1, J16.1, J17.1, J18.1
GND: C1.2, C2.2, C3.2, J1.2, J2.2, Q1.3 (S), Q2.3 (S), Q3.3 (S), Q4.3 (S), Q5.3 (S), Q6.3 (S), Q7.3 (S), Q8.3 (S), Q9.3 (S), Q10.3 (S), Q11.3 (S), Q12.3 (S), Q13.3 (S), Q14.3 (S), Q15.3 (S), Q16.3 (S), R3.1, R4.1, R7.1, R8.1, R11.1, R12.1, R15.1, R16.1, R19.1, R20.1, R23.1, R24.1, R27.1, R28.1, R31.1, R32.1, R33.1, R34.1, R35.1, R37.2, U1.14 (GND), U1.17 (GND)
LED_1: J3.2, Q1.2 (D)
LED_2: J4.2, Q2.2 (D)
LED_3: J5.2, Q3.2 (D)
LED_4: J6.2, Q4.2 (D)
LED_5: J7.2, Q5.2 (D)
LED_6: J8.2, Q6.2 (D)
LED_7: J9.2, Q7.2 (D)
LED_8: J10.2, Q8.2 (D)
LED_9: J11.2, Q9.2 (D)
LED_10: J12.2, Q10.2 (D)
LED_11: J13.2, Q11.2 (D)
LED_12: J14.2, Q12.2 (D)
LED_13: J15.2, Q13.2 (D)
LED_14: J16.2, Q14.2 (D)
LED_15: J17.2, Q15.2 (D)
LED_16: J18.2, Q16.2 (D)
unnamed: D1.2 (A), Q17.3 (D)
unnamed: D1.1 (K), R33.2
unnamed: D2.1 (K), R35.2
unnamed: C2.1, D3.1 (K), D5.1 (K), U2.3 (VI)
unnamed: D4.2 (A), J2.1
unnamed: Q1.1 (G), R1.2, R3.2
unnamed: Q2.1 (G), R2.2, R4.2
unnamed: Q3.1 (G), R5.2, R7.2
unnamed: Q4.1 (G), R6.2, R8.2
unnamed: Q5.1 (G), R9.2, R11.2
unnamed: Q6.1 (G), R10.2, R12.2
unnamed: Q7.1 (G), R13.2, R15.2
unnamed: Q8.1 (G), R14.2, R16.2
unnamed: Q9.1 (G), R17.2, R19.2
unnamed: Q10.1 (G), R18.2, R20.2
unnamed: Q11.1 (G), R21.2, R23.2
unnamed: Q12.1 (G), R22.2, R24.2
unnamed: Q13.1 (G), R25.2, R27.2
unnamed: Q14.1 (G), R26.2, R28.2
unnamed: Q15.1 (G), R29.2, R31.2
unnamed: Q16.1 (G), R30.2, R32.2
unnamed: F1.1, Q17.2 (S), SW1.2 (B)
unnamed: R36.2, R37.1, U2.1 (ADJ)
PWM_1: R1.1, U1.23 (IO5)
PWM_2: R2.1, U1.12 (IO12)
PWM_3: R5.1, U1.13 (IO13)
PWM_4: R6.1, U1.11 (IO14)
PWM_5: R9.1, U1.18 (IO15)
PWM_6: R10.1, U1.21 (IO16)
PWM_7: R13.1, U1.22 (IO17)
PWM_8: R14.1, U1.24 (IO18)
PWM_9: R17.1, U1.25 (IO19)
PWM_10: R18.1, U1.26 (IO21)
PWM_11: R21.1, U1.29 (IO22)
PWM_12: R22.1, U1.30 (IO23)
PWM_13: R25.1, U1.8 (IO25)
PWM_14: R26.1, U1.9 (IO26)
PWM_15: R29.1, U1.10 (IO27)
PWM_16: R30.1, U1.6 (IO32)
esp32_power: D2.2 (A), F1.2, Q17.1 (G), R34.2, U1.15 (VIN)

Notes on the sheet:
5V only in!
power NMOS for low side switching of high currents
ESP32 dev board
Source
Drain
8V - 37V
8V - 37V in / Supply Voltage
power input 5v or 8-37V
Gate
protection circuitry
voltage regulator
16 analog led outputs Common Positive Negative is PWM

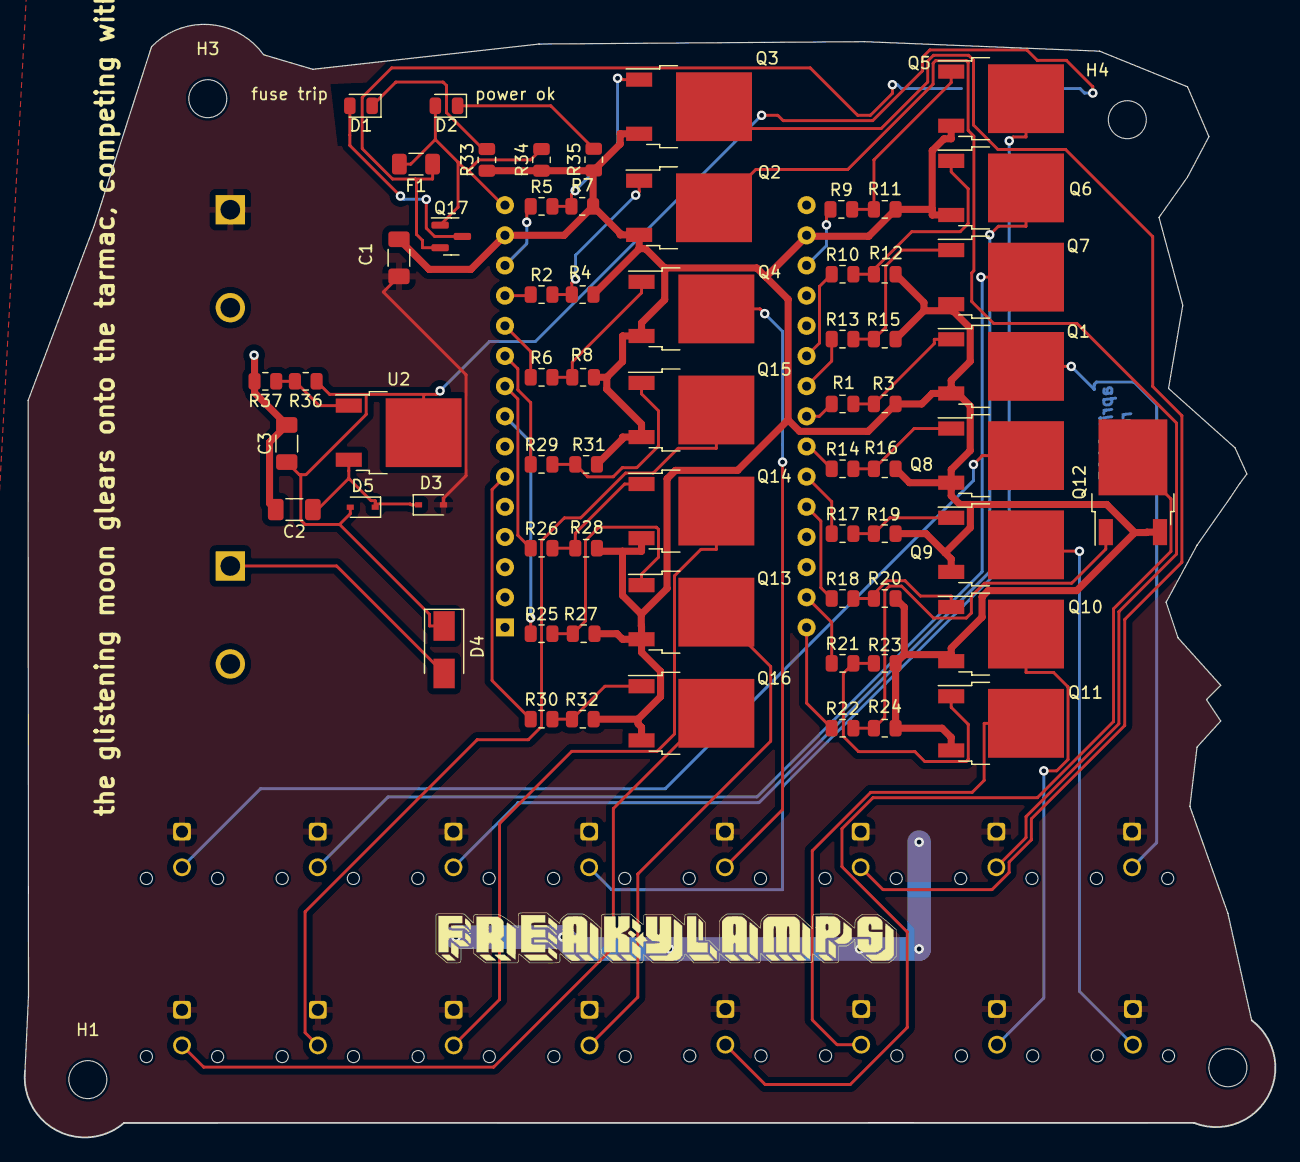
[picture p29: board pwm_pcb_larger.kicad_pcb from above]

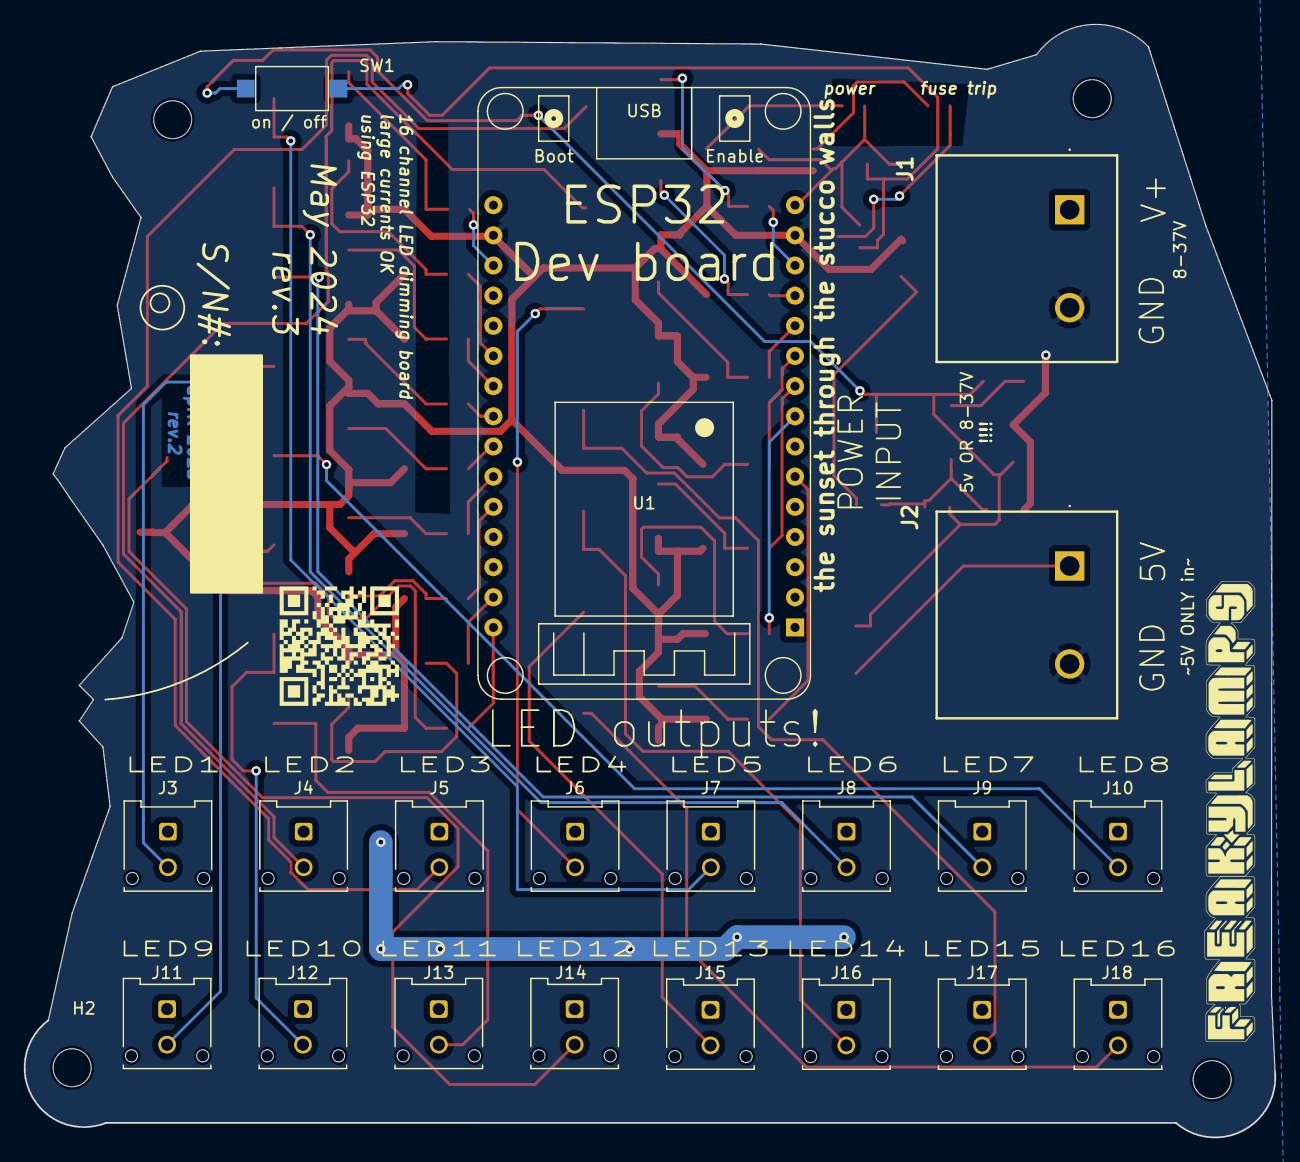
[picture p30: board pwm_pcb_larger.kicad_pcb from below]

Board: 2 copper layers, 105.3 x 93.7 mm, 89 parts (21 on the bottom side), 59 nets.

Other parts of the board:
G1: LOGO; 16_channel_pcb

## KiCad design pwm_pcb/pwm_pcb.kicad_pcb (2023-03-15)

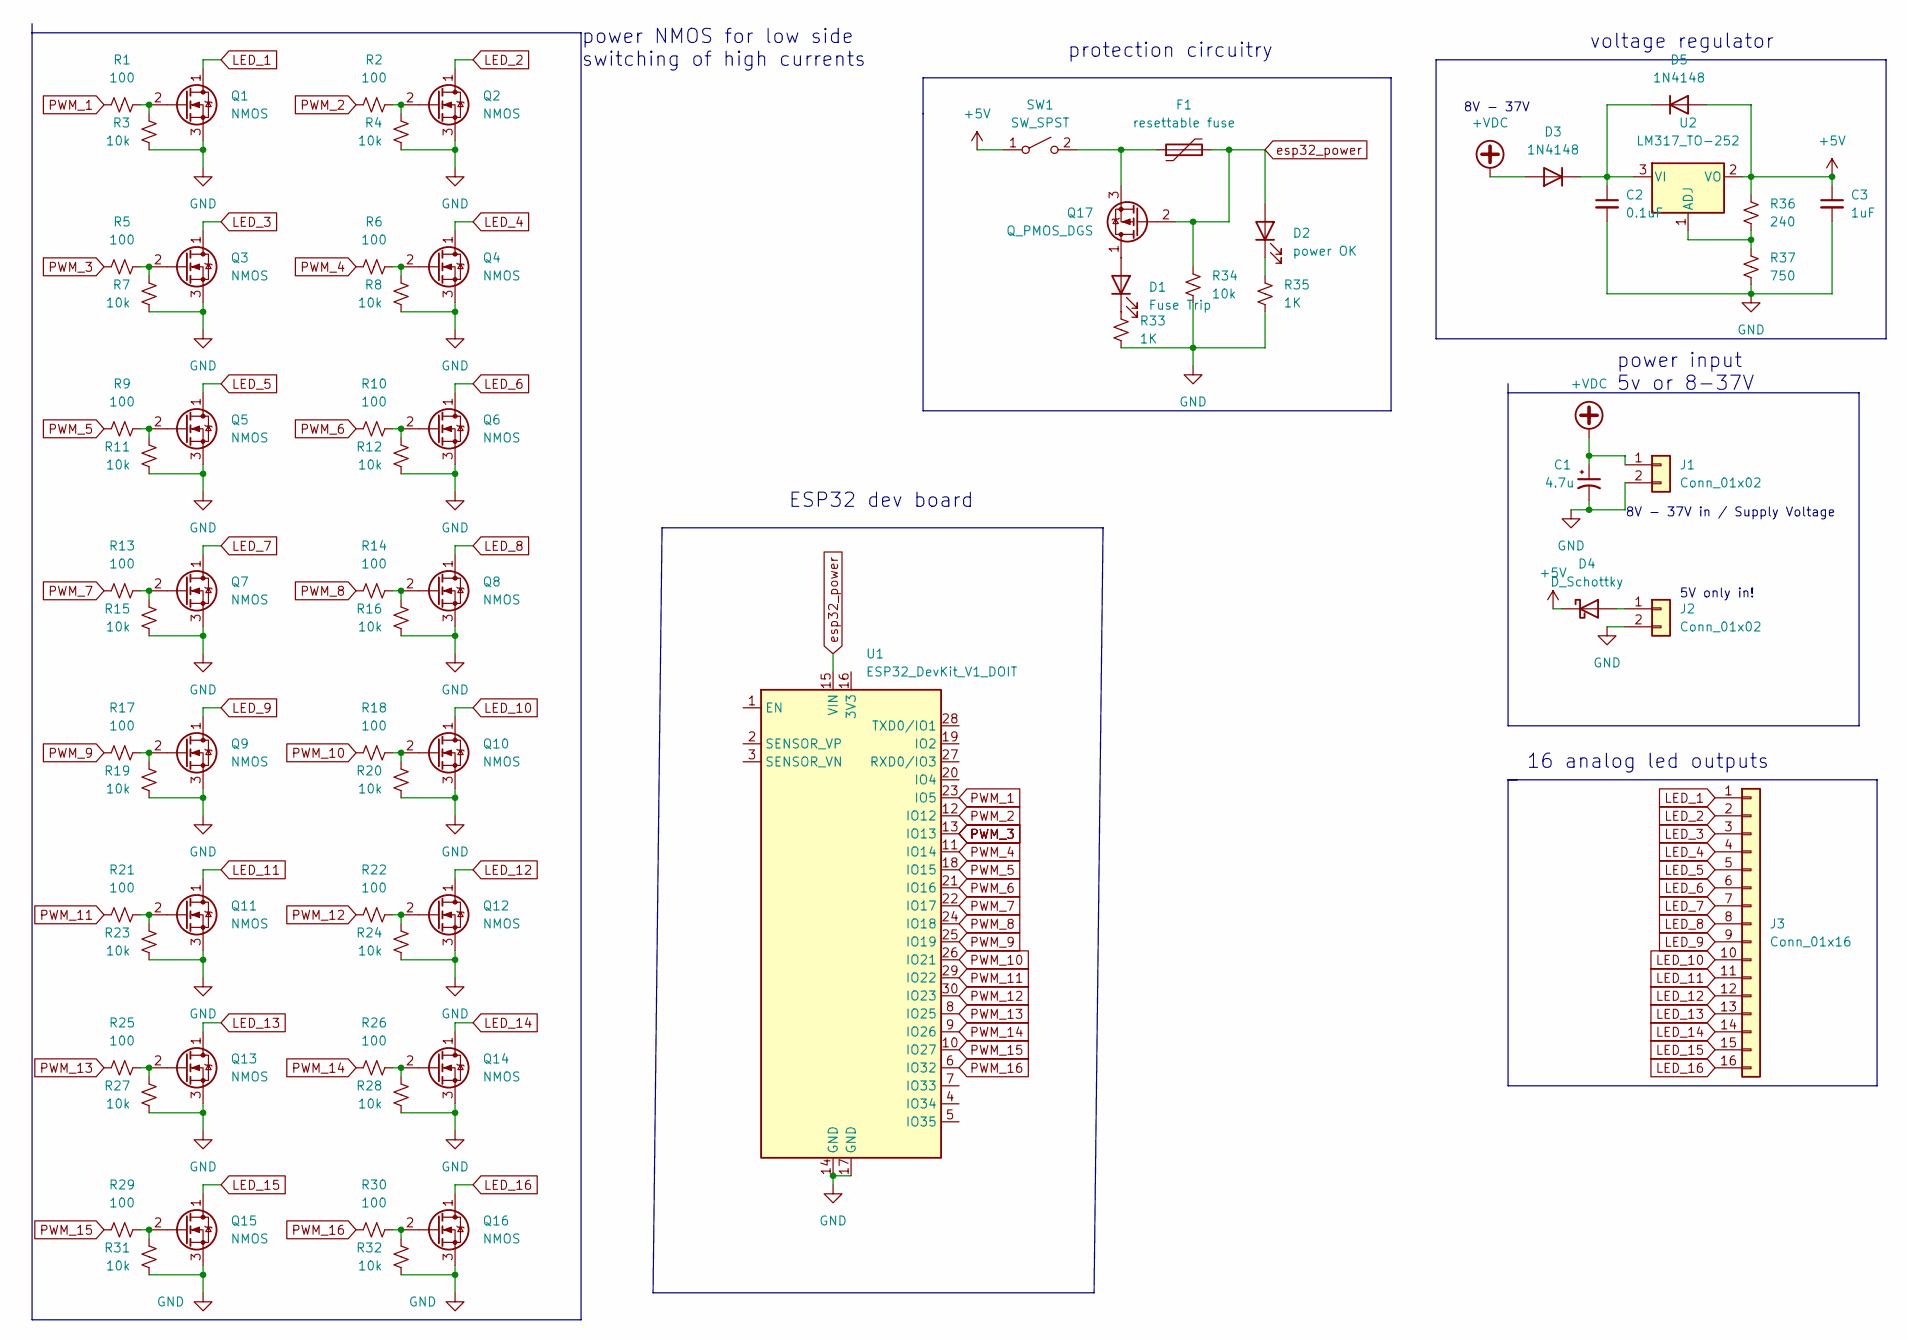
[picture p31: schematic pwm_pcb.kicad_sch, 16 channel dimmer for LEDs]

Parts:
C1: 4.7u; C_1206_3216Metric_Pad1.33x1.80mm_HandSolder; LCSC C29823
C2: 0.1uF; C_1206_3216Metric_Pad1.33x1.80mm_HandSolder; LCSC C24497
C3: 1uF; C_1206_3216Metric_Pad1.33x1.80mm_HandSolder; LCSC C1848
D1: Fuse Trip; LED_1206_3216Metric; LCSC C84256
D2: power OK; LED_1206_3216Metric; LCSC C2297
D3, D5: 1N4148; D_SOD-323; LCSC C2128
D4: D_Schottky; D_SMA; LCSC C2480
F1: resettable fuse; Fuse_1206_3216Metric; LCSC C192524
J1, J2: Conn_01x02; PhoenixContact_MSTBVA_2,5_2-G-5,08_1x02_P5.08mm_Vertical
J3: Conn_01x16; PinHeader_1x16_P2.54mm_Vertical
Q1, Q2, Q3, Q4, Q5, Q6, Q7, Q8, Q9, Q10, Q11, Q12, Q13, Q14, Q15, Q16: NMOS; SOT-23; LCSC C20917
Q17: Q_PMOS_DGS; SOT-23; LCSC C15127
R1, R2, R5, R6, R9, R10, R13, R14, R17, R18, R21, R22, R25, R26, R29, R30: 100; R_0805_2012Metric; LCSC C17408
R3, R4, R7, R8, R11, R12, R15, R16, R19, R20, R23, R24, R27, R28, R31, R32, R34: 10k; R_0805_2012Metric; LCSC C17414
R33, R35: 1K; R_0805_2012Metric; LCSC C17513
R36: 240; R_0805_2012Metric; LCSC C17572
R37: 750; R_0805_2012Metric; LCSC C17818
SW1: SW_SPST; SW_SPST_CK_RS282G05A3; LCSC C54948
U1: ESP32_DevKit_V1_DOIT; esp32_devkit_v1_doit
U2: LM317_TO-252; TO-252-2; LCSC C75510

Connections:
+5V: C3.1, D4.1 (K), D5.2 (A), R36.1, SW1.1 (A), U2.2 (VO)
+VDC: C1.1, D3.2 (A), J1.1
GND: C1.2, C2.2, C3.2, J1.2, J2.2, Q1.3 (S), Q2.3 (S), Q3.3 (S), Q4.3 (S), Q5.3 (S), Q6.3 (S), Q7.3 (S), Q8.3 (S), Q9.3 (S), Q10.3 (S), Q11.3 (S), Q12.3 (S), Q13.3 (S), Q14.3 (S), Q15.3 (S), Q16.3 (S), R3.1, R4.1, R7.1, R8.1, R11.1, R12.1, R15.1, R16.1, R19.1, R20.1, R23.1, R24.1, R27.1, R28.1, R31.1, R32.1, R33.1, R34.1, R35.1, R37.2, U1.14 (GND), U1.17 (GND)
LED_1: J3.1, Q1.1 (D)
LED_2: J3.2, Q2.1 (D)
LED_3: J3.3, Q3.1 (D)
LED_4: J3.4, Q4.1 (D)
LED_5: J3.5, Q5.1 (D)
LED_6: J3.6, Q6.1 (D)
LED_7: J3.7, Q7.1 (D)
LED_8: J3.8, Q8.1 (D)
LED_9: J3.9, Q9.1 (D)
LED_10: J3.10, Q10.1 (D)
LED_11: J3.11, Q11.1 (D)
LED_12: J3.12, Q12.1 (D)
LED_13: J3.13, Q13.1 (D)
LED_14: J3.14, Q14.1 (D)
LED_15: J3.15, Q15.1 (D)
LED_16: J3.16, Q16.1 (D)
unnamed: C2.1, D3.1 (K), D5.1 (K), U2.3 (VI)
unnamed: D1.1 (K), R33.2
unnamed: D1.2 (A), Q17.1 (D)
unnamed: D2.1 (K), R35.2
unnamed: D4.2 (A), J2.1
unnamed: F1.1, Q17.3 (S), SW1.2 (B)
unnamed: Q1.2 (G), R1.2, R3.2
unnamed: Q2.2 (G), R2.2, R4.2
unnamed: Q3.2 (G), R5.2, R7.2
unnamed: Q4.2 (G), R6.2, R8.2
unnamed: Q5.2 (G), R9.2, R11.2
unnamed: Q6.2 (G), R10.2, R12.2
unnamed: Q7.2 (G), R13.2, R15.2
unnamed: Q8.2 (G), R14.2, R16.2
unnamed: Q9.2 (G), R17.2, R19.2
unnamed: Q10.2 (G), R18.2, R20.2
unnamed: Q11.2 (G), R21.2, R23.2
unnamed: Q12.2 (G), R22.2, R24.2
unnamed: Q13.2 (G), R25.2, R27.2
unnamed: Q14.2 (G), R26.2, R28.2
unnamed: Q15.2 (G), R29.2, R31.2
unnamed: Q16.2 (G), R30.2, R32.2
unnamed: R36.2, R37.1, U2.1 (ADJ)
PWM_1: R1.1, U1.23 (IO5)
PWM_2: R2.1, U1.12 (IO12)
PWM_3: R5.1, U1.13 (IO13)
PWM_4: R6.1, U1.11 (IO14)
PWM_5: R9.1, U1.18 (IO15)
PWM_6: R10.1, U1.21 (IO16)
PWM_7: R13.1, U1.22 (IO17)
PWM_8: R14.1, U1.24 (IO18)
PWM_9: R17.1, U1.25 (IO19)
PWM_10: R18.1, U1.26 (IO21)
PWM_11: R21.1, U1.29 (IO22)
PWM_12: R22.1, U1.30 (IO23)
PWM_13: R25.1, U1.8 (IO25)
PWM_14: R26.1, U1.9 (IO26)
PWM_15: R29.1, U1.10 (IO27)
PWM_16: R30.1, U1.6 (IO32)
esp32_power: D2.2 (A), F1.2, Q17.2 (G), R34.2, U1.15 (VIN)

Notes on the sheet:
5V only in!
power NMOS for low side switching of high currents
ESP32 dev board
8V - 37V
8V - 37V in / Supply Voltage
power input 5v or 8-37V
protection circuitry
voltage regulator
16 analog led outputs

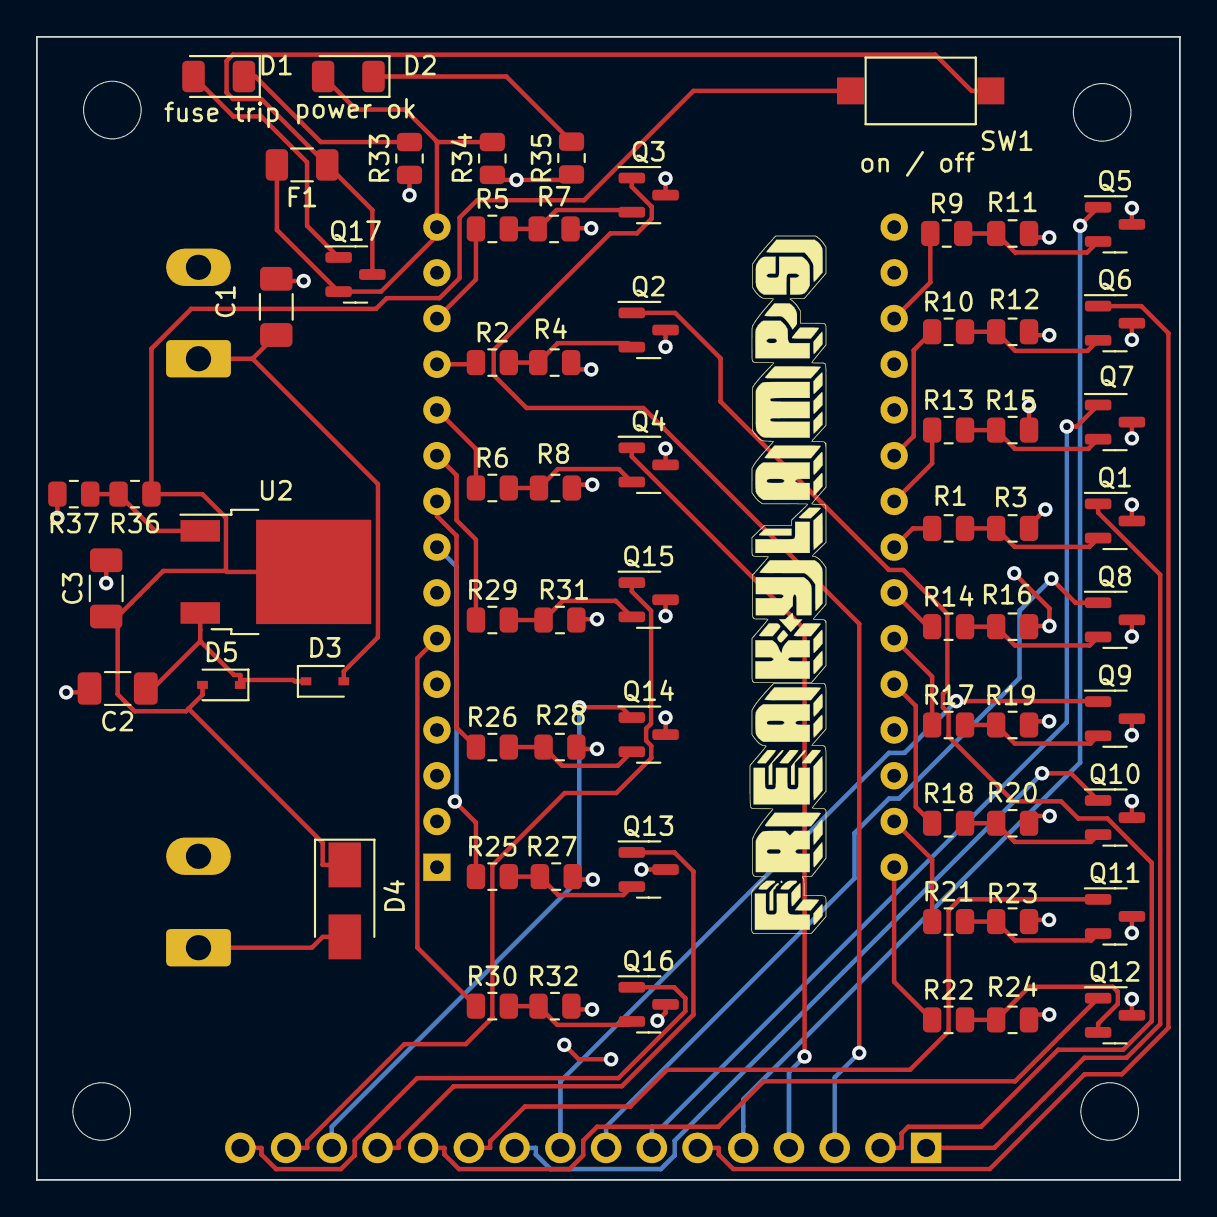
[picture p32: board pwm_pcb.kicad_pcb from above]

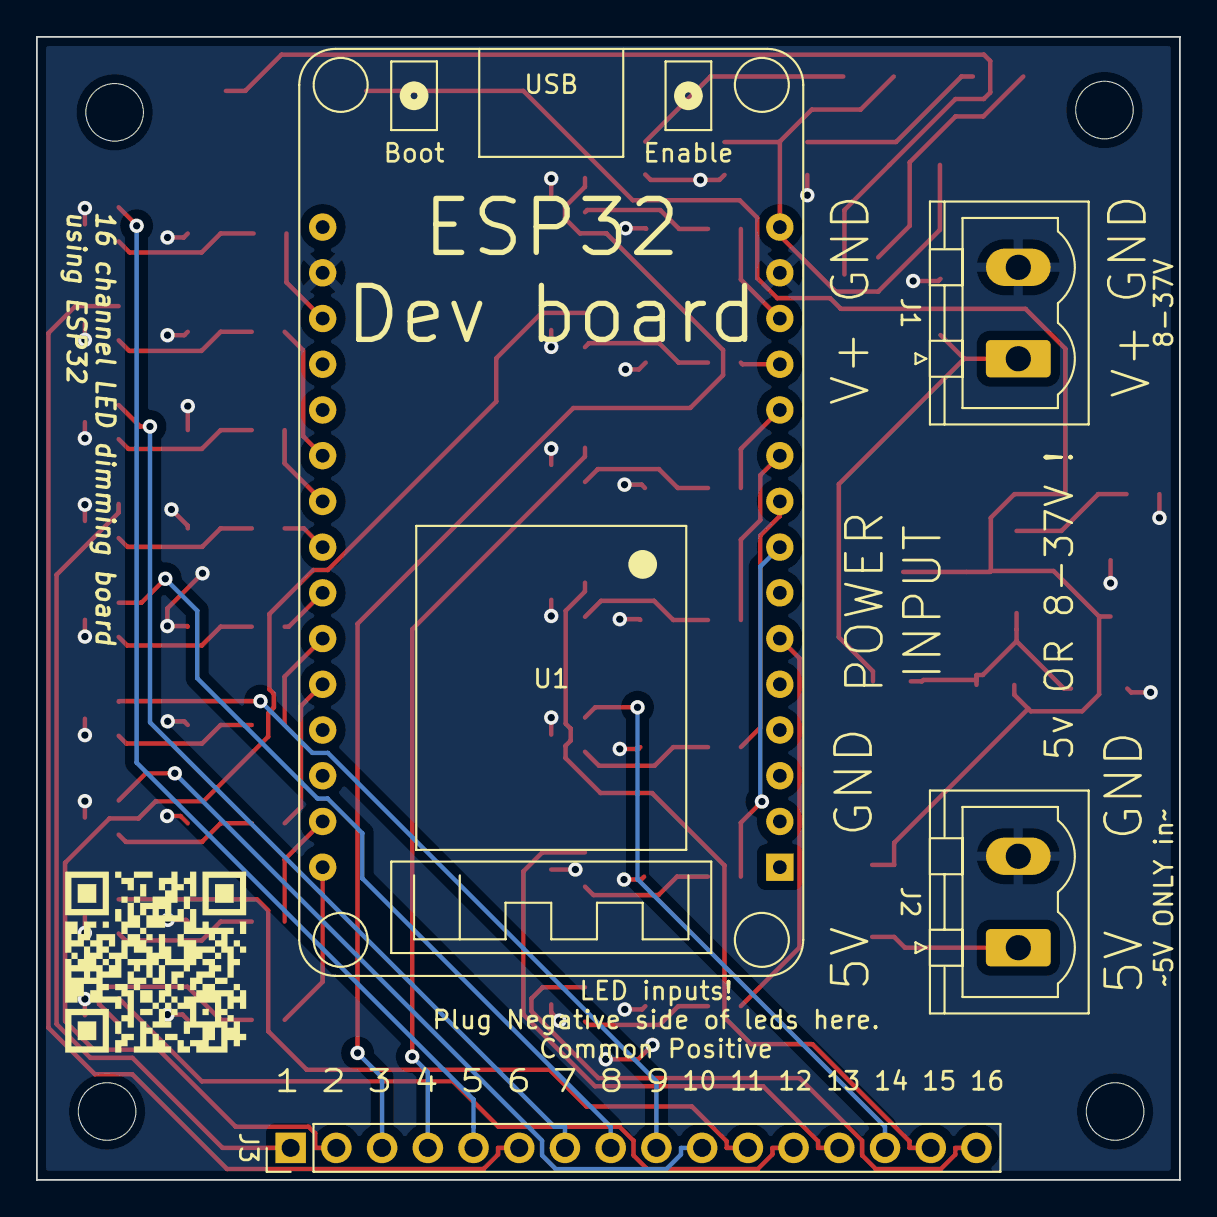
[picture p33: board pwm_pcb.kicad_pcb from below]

Board: 2 copper layers, 63.5 x 63.5 mm, 74 parts (5 on the bottom side), 59 nets.

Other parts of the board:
G1: LOGO; 16_channel_pcb
MH1, MH2, MH3, MH4: MountingHole_3.2mm_M3

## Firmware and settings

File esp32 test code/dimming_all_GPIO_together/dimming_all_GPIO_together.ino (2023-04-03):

const int ledPins[16] = {5, 12, 13, 14, 15, 16, 17, 18, 19, 21, 22, 23, 25, 26, 27, 32};
int pinCount = 16;

// setting PWM properties
const int freq = 5000;
const int ledChannel = 0;
const int resolution = 8;

void setup() {
  // configure LED PWM functionalitites
  ledcSetup(ledChannel, freq, resolution);

  // attach the channel to the GPIO to be controlled
  for (int thisPin = 0; thisPin < pinCount; thisPin++) {
    ledcAttachPin(ledPins[thisPin], ledChannel);
  }
}

void loop() {
  // iterate over the pins:
  for (int thisPin = 0; thisPin < pinCount; thisPin++) {
    // fade the LED on thisPin from off to brightest:
    for (int brightness = 0; brightness < 255; brightness++) {
      ledcWrite(ledChannel, brightness);
      delay(2);
    }
    // fade the LED on thisPin from brightest to off:
    for (int brightness = 255; brightness >= 0; brightness--) {
      ledcWrite(ledChannel, brightness);
      delay(2);
    }
    // pause between LEDs:
    delay(100);
  }
}

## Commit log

2023-03-20 adding larger pcb
    [BOM-pwm_pcb.csv, BOM-pwm_pcb_larger.csv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]
2023-03-27 adding parts ref to readme
    [Lower.stl, PCBPWM v4.f3d, Upper.stl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]
2023-04-03 adding test code and 3d print files
    [larger_enclosure_base.stl, larger_enclosure_lid.stl, pwm_pcb.kicad_sch]
2023-04-06 updating v2 of pcb
    [BOM-pwm_pcb.csv, BOM-pwm_pcb_v2.csv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]
2023-04-14 updates to the enclosure file
    [PCBPWM v4.f3d, PCBPWM_v2.f3d, base_w3mmTolerance.stl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]
2023-04-15 adding pinout on readme
    [PCBPWM_v2 v1.f3d, pwmpcb_v3_w3mmToleranceLID.3mf]
2024-05-21 starting rev b with new connectors
    [pwm_pcb_largerREVA.kicad_sch]
2024-05-22 updating the new rev board with new connectors for led outputs and PSU input
    [pwm_pcb_larger.kicad_pcb, pwm_pcb_larger.kicad_sch]
2024-05-22 rev 3 finished and sent to JLC for fab
    [BOM-pwm_pcb_larger.csv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]
2024-05-22 small change
    [pwm_pcb_larger.kicad_sch]
2024-05-23 making BOM
    [pwm_pcb_larger.kicad_sch, pwm_pcb_largerREV3.csv]
2024-05-23 adding readme BOM stuff
    [pwm_pcb_largerREV3.csv]
2024-05-30 adding keepout zone to areas that are supposed to be FR4
    [pwm_pcb_larger.kicad_pcb]
